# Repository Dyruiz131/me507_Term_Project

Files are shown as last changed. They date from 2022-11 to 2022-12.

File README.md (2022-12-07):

# ME507 Fall 2022 Project: ChessBot

[ChessBot controller code documentation](https://dyruiz131.github.io/me507_Term_Project/)

[ChessBot controller code](https://github.com/Dyruiz131/me507_Term_Project/tree/main/Chessbot)

[ChessBot server repository](https://github.com/sam-hud/ME507-ChessBotServer)

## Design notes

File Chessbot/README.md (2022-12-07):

# ME507 Fall 2022 Project: Chessbot

## Introduction
The project aims to allow two online users to play against each other on a robotically controlled board.

## Documentation
The documentation for the code can be found here:
[ChessBot controller documentation](https://dyruiz131.github.io/me507_Term_Project)

## Webserver
The website controls a custom built API, which the ESP32 communicates with to manage changes to the board.

The webserver repository can be found here:
[ME507-ChessBotServer](https://github.com/sam-hud/ME507-ChessBotServer)

The controller website for the board can accessed [here](https://me507-chessbot.netlify.app).

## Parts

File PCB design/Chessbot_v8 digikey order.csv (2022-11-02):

CART | Qty | Value | Device | Package | Parts | Description | AVAILABILITY | CATEGORY | DESCRIPTION | HEIGHT | MANUFACTURER | MANUFACTURER_NAME | MANUFACTURER_PART_NUMBER | MF | MOUSER_PART_NUMBER | MOUSER_PRICE-STOCK | MP | MPN | OC_FARNELL | OC_NEWARK | OPERATING_TEMP | OPERATING_TEMPERATURE | PACKAGE | PART_STATUS | POPULARITY | PRICE | PURCHASE-URL | ROHS_COMPLIANCE | ROHS_COMPLIANT | SERIES | SPICEPREFIX | SUB-CATEGORY | THERMALLOSS | TYPE
3 | 1 |  | BEAD0805 | 805 | B1 | Ferrite Bead
3 | 1 |  | DCJ0303 | DCJ0303 | 12V_DC | DC POWER JACK |  |  |  |  |  |  |  |  |  |  |  |  | unknown | unknown |  |  |  |  | 20
3 | 1 |  | LEDSMT1206 | 1206 | LED1 | LED |  |  |  |  |  |  |  |  |  |  |  |  |  |  |  |  |  |  | 20
amazon | 1 |  | PINHD-2X2 | 2X02 | LSWITCH | PIN HEADER |  |  |  |  |  |  |  |  |  |  |  |  |  |  |  |  |  |  | 0
10 | 3 | 0.1uF | C-USC0805 | C0805 | C3, C4, C5 | CAPACITOR, American symbol |  |  |  |  |  |  |  |  |  |  |  |  |  |  |  |  |  |  | 63 |  |  |  |  |  | C
10 | 2 | 100uF | CPOL-USE2.5-6 | E2,5-6 | C1, C2 | POLARIZED CAPACITOR, American symbol |  |  |  |  |  |  |  |  |  |  |  |  |  |  |  |  |  |  | 14 |  |  |  |  |  | C
10 | 1 | 100Ω | R-US_R0805 | R0805 | R5 | RESISTOR, American symbol |  |  |  |  |  |  |  |  |  |  |  |  |  |  |  |  |  |  | 85 |  |  |  |  |  | R
10 | 1 | 10kΩ | PV36Z | PV36Z | R1 | Rectangular Trimmer Potentiometers - PV36 Series |  | Resistor | Lead Sealed Type Multiturn PV36 Series |  | BOURNS |  |  |  |  |  |  | PV36Z |  |  |  | -55 to +125 °C |  | Active |  |  |  | RoHS Compliant |  | PV36 |  | Trimpot |  | Lead Sealed
10 | 4 | 10kΩ | R-US_R0805 | R0805 | R2, R6, R7, R8 | RESISTOR, American symbol |  |  |  |  |  |  |  |  |  |  |  |  |  |  |  |  |  |  | 85 |  |  |  |  |  | R
10 | 1 | 180Ω | R-US_R0805 | R0805 | R3 | RESISTOR, American symbol |  |  |  |  |  |  |  |  |  |  |  |  |  |  |  |  |  |  | 85 |  |  |  |  |  | R
10 | 2 | 1N4004 | 1N4004 | DO41-10 | D1, D2 | DIODE |  |  |  |  |  |  |  |  |  |  |  |  |  |  |  |  |  |  | 82
10 | 1 | 1kΩ | R-US_R0805 | R0805 | R4 | RESISTOR, American symbol |  |  |  |  |  |  |  |  |  |  |  |  |  |  |  |  |  |  | 85 |  |  |  |  |  | R
n/a | 1 | KEEYEES_ESP32 | KEEYEES_ESP32 | KEEYEES_ESP32 | ESP32 | Footprint for an add-on board (shield, hat, etc.) for a KeeYees ESP32 development board with ESP-WROOM-32 module. 38 pins.
3 | 1 | LM393D | LM393D | LM393D | U$2
amazon | 2 | PINHD-1X2 | PINHD-1X2 | 1X02 | 5V_JUMP, ELECTROMAGNET | PIN HEADER |  | CONNECTOR |  |  |  |  |  |  |  |  |  |  |  |  |  |  |  |  |  |  |  |  |  |  |  | PIN-HEADER
amazon | 3 | PINHD-1X4 | PINHD-1X4 | 1X04 | MPM3610, STEPPER1, STEPPER2 | PIN HEADER |  | CONNECTOR |  |  |  |  |  |  |  |  |  |  |  |  |  |  |  |  |  |  |  |  |  |  |  | PIN-HEADER
amazon | 1 | PINHD-2X2 | PINHD-2X2 | 2X02 | TCRT5000 | PIN HEADER |  | CONNECTOR |  |  |  |  |  |  |  |  |  |  |  |  |  |  |  |  |  |  |  |  |  |  |  | PIN-HEADER
4 | 1 | PMV16XNR | PMV16XNR | SOT95P230X110-3N | Q1 | Nexperia PMV16XNR N-channel MOSFET, 8.6 A, 20 V PMV16XN, 3-Pin SOT-23 |  |  | Nexperia PMV16XNR N-channel MOSFET, 8.6 A, 20 V PMV16XN, 3-Pin SOT-23 | 1.1mm |  | Nexperia | PMV16XNR |  | 771-PMV16XNR | https://www.mouser.co.uk/ProductDetail/Nexperia/PMV16XNR?qs=%252BRKXB2WKlSfp5fVW5DDV6w%3D%3D
amazon | 2 | TMC2208_SILENTSTEPSTICK | TMC2208_SILENTSTEPSTICK | MODULE_TMC2208_SILENTSTEPSTICK | DRIVER1, DRIVER2 | TMC2208 Motor Controller/Driver, Stepper Power Management Evaluation Board Check availability | In Stock |  | TMC2208 Motor Controller/Driver, Stepper Power Management Evaluation Board |  |  |  |  | Trinamic Motion |  |  | TMC2208 SILENTSTEPSTICK |  |  |  |  |  | None |  |  | None | https://pricing.snapeda.com/search/part/TMC2208 SILENTSTEPSTICK/?ref=eda

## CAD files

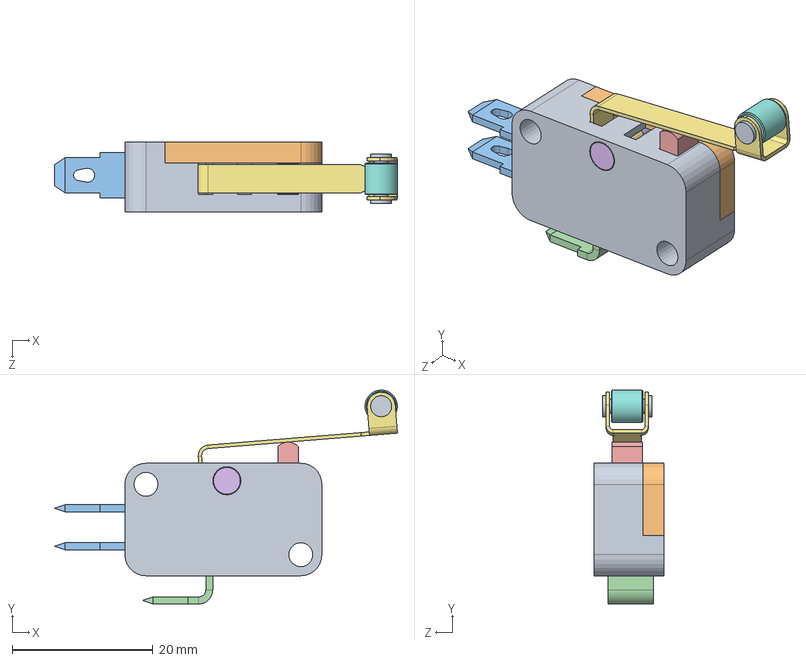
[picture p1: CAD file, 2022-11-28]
CAD/Assembly - V-156-1C25 micro switch.SLDASM
48.7 x 30.4 x 10.0 mm
Cover
Connector - straight x 2
Connector - bent
Switch
Rivet - long
Arm
Roll
Rivet - short

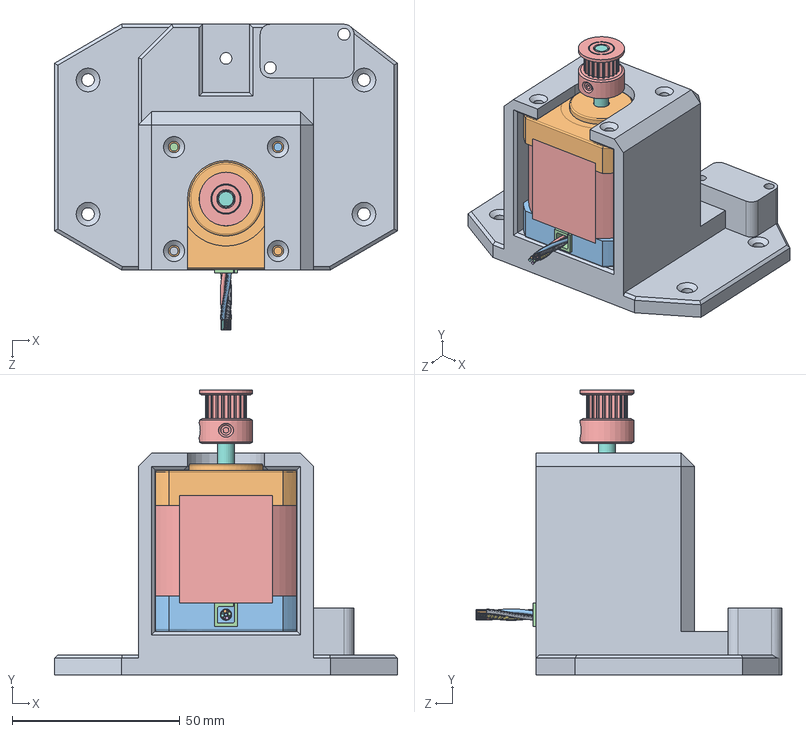
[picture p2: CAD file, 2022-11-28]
CAD/Stepper mount assembly.SLDASM
102.3 x 85.0 x 91.1 mm
platform rail mount stepper
Frontplate.step
Backplate.step
Connenctor.step
Housing.step
Bearing dummy.step
Bearing dummy 01.step
Core.step
M3x40-Screw.step
M3x40-Screw001.step
M3x40-Screw002.step
M3x40-Screw003.step
Cable-1of4.step
Copper-1of4.step
Cable-2of4.step
Copper-4of4.step
Cable-3of4.step
Copper-3of4.step
Cable-4of4.step
Copper-2of4.step
GT2_20T

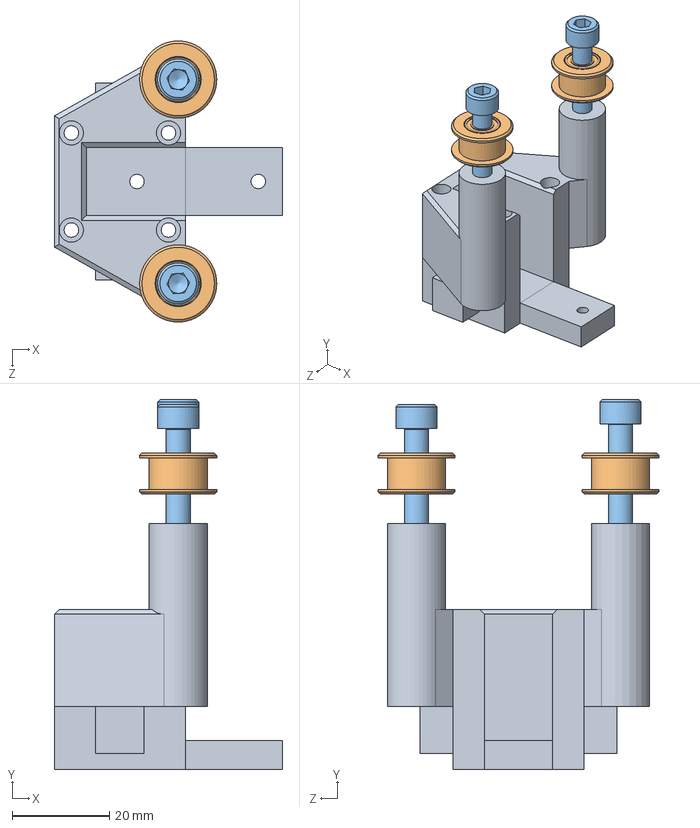
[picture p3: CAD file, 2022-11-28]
CAD/rail to rail sliding idler mount assembly.SLDASM
47.0 x 76.2 x 57.9 mm
rail rail mount
GT2 idler pulley (5 mm bore) v1 x 2
socket head cap screw_am x 2

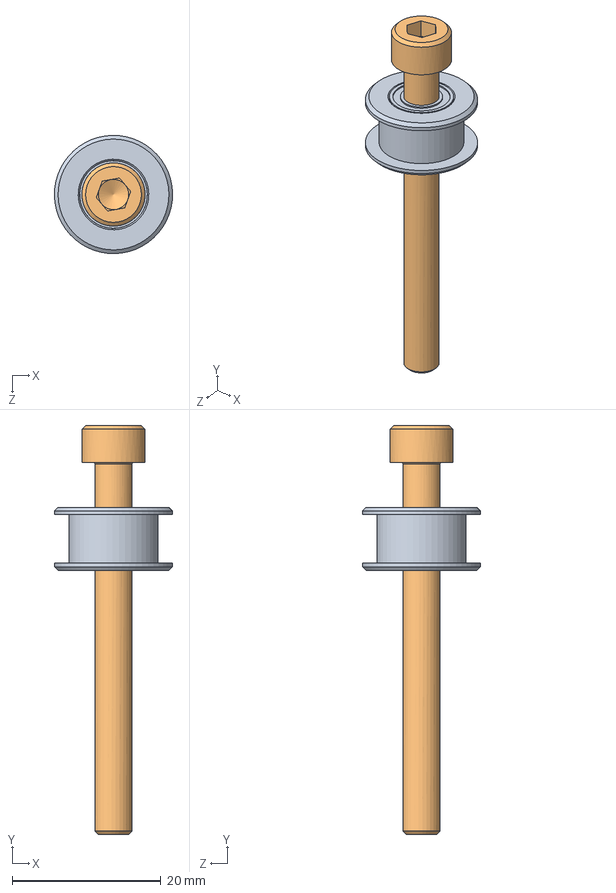
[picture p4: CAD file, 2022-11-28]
CAD/platform idler mount assembly.SLDASM
15.9 x 55.0 x 15.9 mm
GT2 idler pulley (5 mm bore) v1
socket head cap screw_am

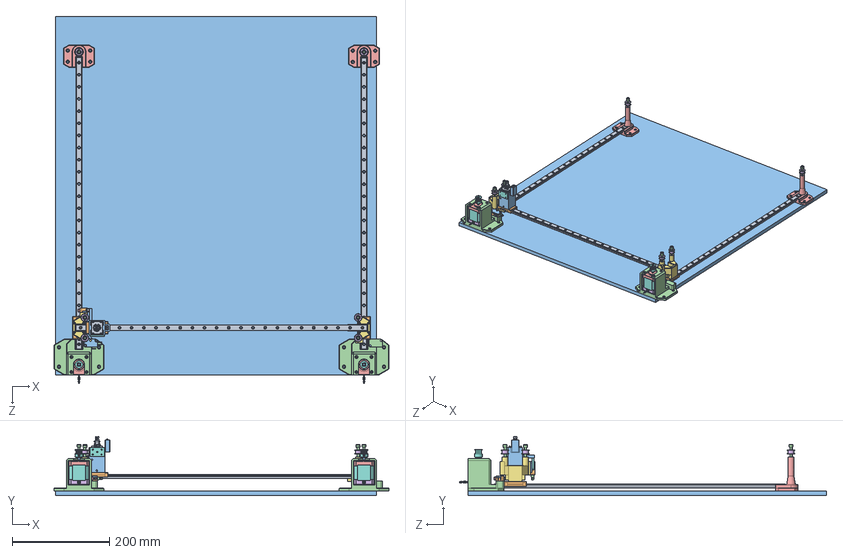
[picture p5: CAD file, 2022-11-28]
CAD/507_Chess_Bot.SLDASM
689.3 x 122.0 x 755.8 mm
MGN12 LINEAR GUIDE RAIL, 600 mm x 3
MGN12H, LINEAR GUIDE BLOCK x 3
platform rail mount stepper x 2
Frontplate.step x 2
Backplate.step x 2
Connenctor.step x 2
Housing.step x 2
Bearing dummy.step x 2
Bearing dummy 01.step x 2
Core.step x 2
M3x40-Screw.step x 2
M3x40-Screw001.step x 2
M3x40-Screw002.step x 2
M3x40-Screw003.step x 2
Cable-1of4.step x 2
Copper-1of4.step x 2
Cable-2of4.step x 2
Copper-4of4.step x 2
Cable-3of4.step x 2
Copper-3of4.step x 2
Cable-4of4.step x 2
Copper-2of4.step x 2
GT2_20T x 2
Solenoid JF-0826B
Cover x 2
Connector - straight x 4
Connector - bent x 2
Switch x 2
Rivet - long x 2
Arm x 2
Roll x 2
Rivet - short x 2
Solenoid Mount
socket head cap screw_am x 7
platform rail mount x 2
GT2 idler pulley (5 mm bore) v1 x 6
rail rail mount x 2
Belt Clamp
TCR5000L

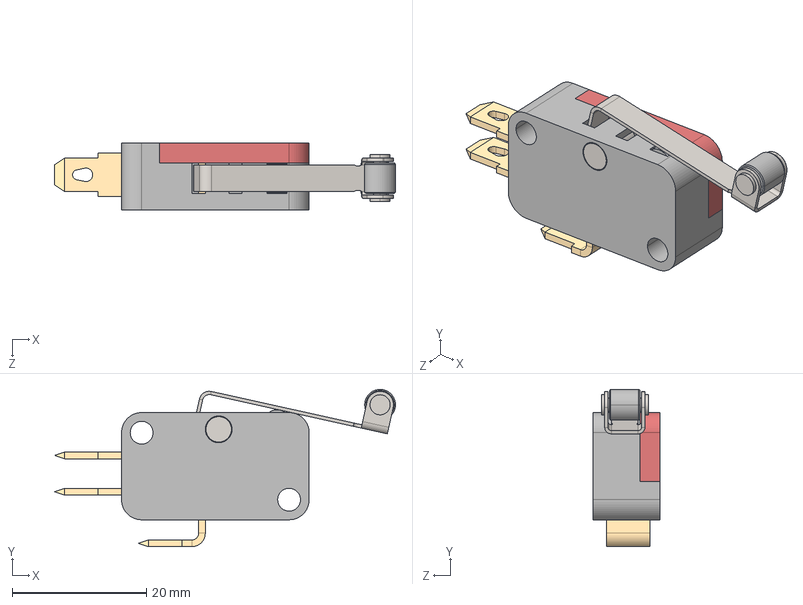
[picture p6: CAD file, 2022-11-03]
CAD/V-156-1C25/Assembly - V-156-1C25 micro switch (Pressed).STEP
50.9 x 23.5 x 10.0 mm
Cover
Connector - straight x 2
Connector - bent
Switch
Rivet - long
Arm
Roll
Rivet - short

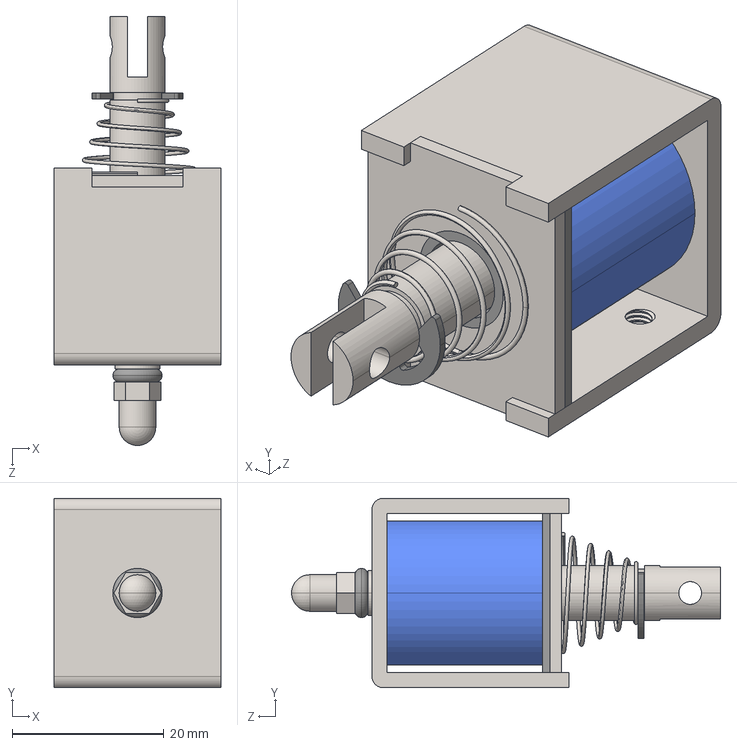
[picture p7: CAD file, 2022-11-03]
CAD/linear actuator/Solenoid JF-0826B.STEP
22.0 x 25.0 x 56.6 mm

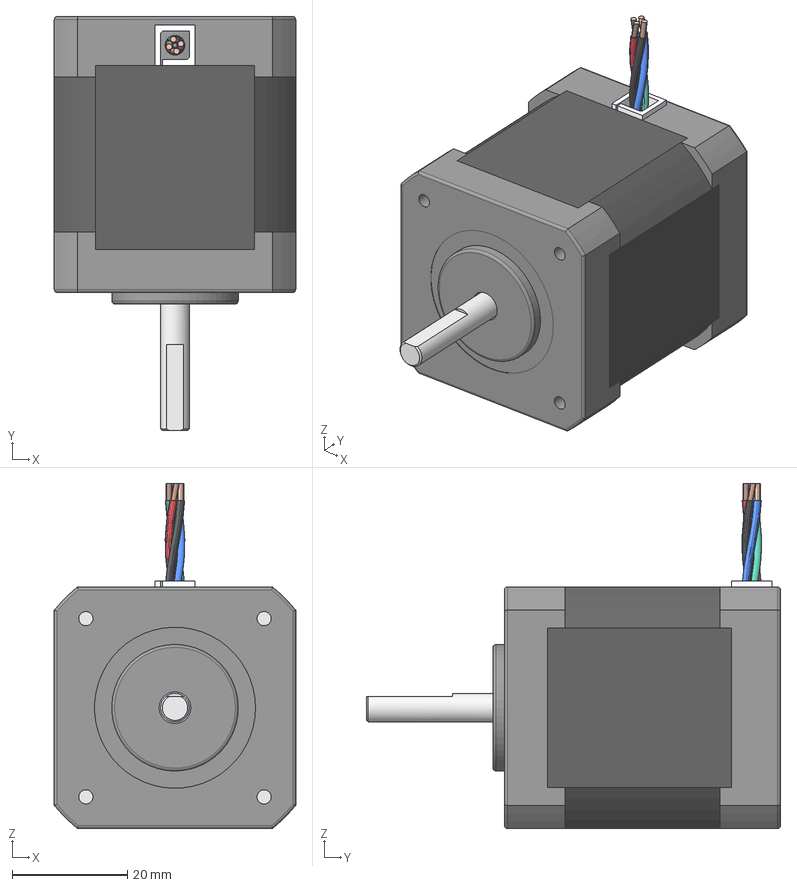
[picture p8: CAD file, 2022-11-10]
CAD/nema17-x-48-1/NEMA17 x 48.step
42.0 x 72.0 x 60.0 mm
Frontplate
Backplate
Connenctor
Housing
Bearing dummy
Bearing dummy 01
Core
M3x40-Screw
M3x40-Screw001
M3x40-Screw002
M3x40-Screw003
Cable-1of4
Copper-1of4
Cable-2of4
Copper-4of4
Cable-3of4
Copper-3of4
Cable-4of4
Copper-2of4

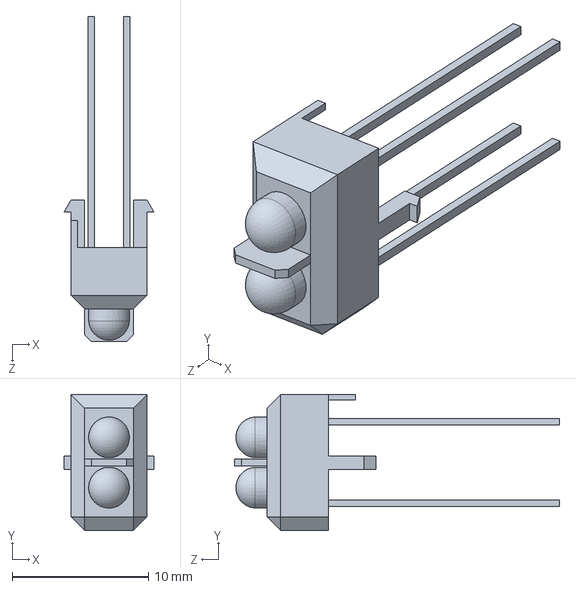
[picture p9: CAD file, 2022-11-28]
CAD/TCRT5000L/tcrt5000l-1/TCR5000L.SLDPRT
6.60 x 10.0 x 23.9 mm

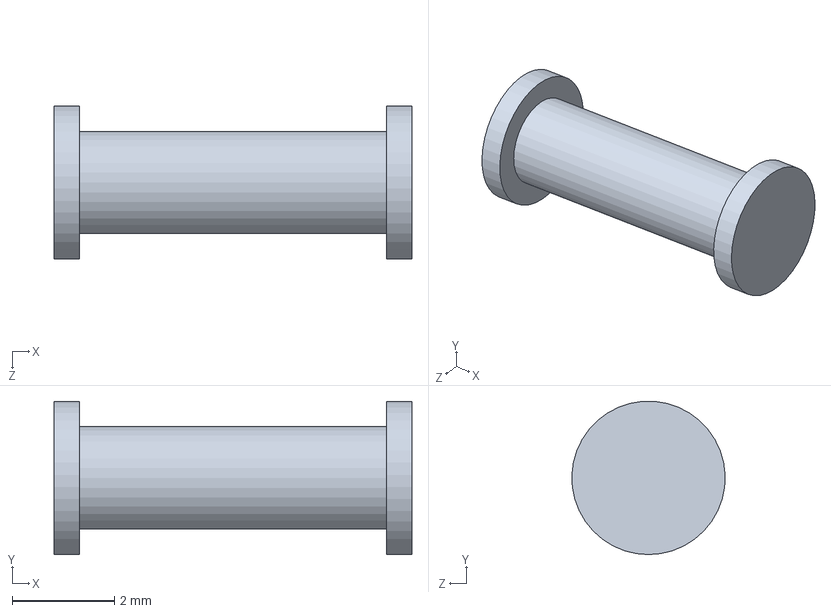
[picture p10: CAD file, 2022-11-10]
CAD/V-156-1C25/Rivet - short.SLDPRT
7.00 x 3.00 x 3.00 mm

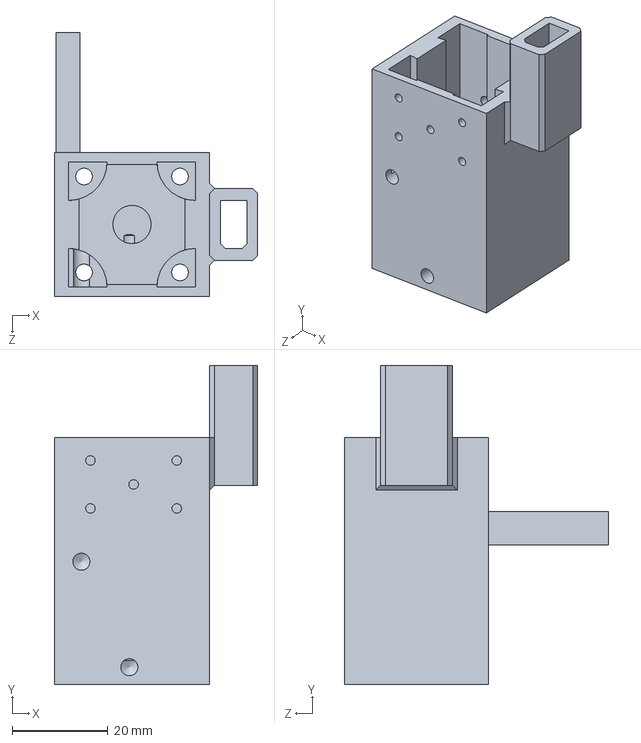
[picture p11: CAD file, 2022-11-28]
CAD/Solenoid Mount.SLDPRT
42.4 x 66.5 x 55.0 mm

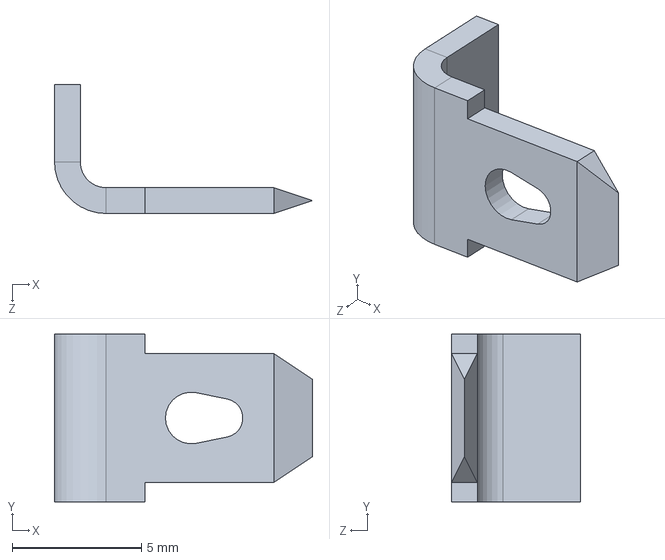
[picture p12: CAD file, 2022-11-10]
CAD/V-156-1C25/Connector - bent.SLDPRT
10.0 x 6.50 x 5.00 mm

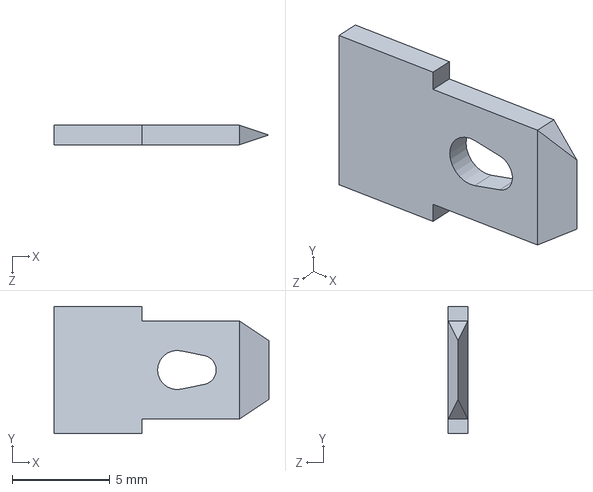
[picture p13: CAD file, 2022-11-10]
CAD/V-156-1C25/Connector - straight.SLDPRT
11.0 x 6.50 x 1.00 mm

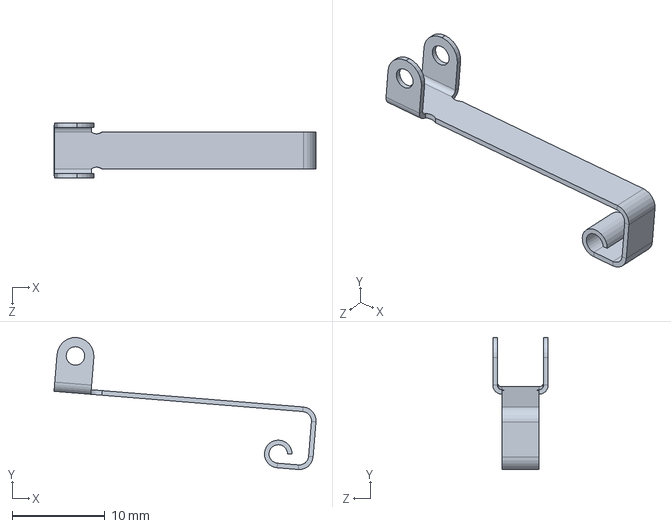
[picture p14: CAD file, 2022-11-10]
CAD/V-156-1C25/Arm.SLDPRT
28.3 x 14.3 x 6.00 mm

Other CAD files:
CAD/V-156-1C25/Assembly - V-156-1C25 micro switch.SLDASM
CAD/V-156-1C25/Assembly - V-156-1C25 micro switch (Idle).STEP
CAD/V-156-1C25/Roll.SLDPRT
CAD/rail rail mount.SLDPRT
CAD/Belt Clamp.SLDPRT
CAD/Belt Clamp.STL
CAD/GT2 idler pulley (5 mm bore) v1.SLDPRT
CAD/GT2_20T.SLDPRT
CAD/MGN12 LINEAR GUIDE RAIL, 600 mm.SLDPRT
CAD/MGN12H, LINEAR GUIDE BLOCK.SLDPRT
CAD/Solenoid Mount.STL
CAD/V-156-1C25/Body.SLDPRT
CAD/V-156-1C25/Cover.SLDPRT
CAD/V-156-1C25/Rivet - long.SLDPRT
CAD/V-156-1C25/Switch.SLDPRT
CAD/game board.SLDPRT
CAD/linear actuator/Solenoid JF-0826B.SLDPRT
CAD/nema17-x-48-1/NEMA17 x 48.SLDASM
CAD/platform base.SLDPRT
CAD/platform rail mount stepper bracket.SLDPRT
CAD/platform rail mount stepper.SLDPRT
CAD/platform rail mount stepper1.STL
CAD/platform rail mount stepper2.STL
CAD/platform rail mount.SLDPRT
CAD/platform rail mount1.STL

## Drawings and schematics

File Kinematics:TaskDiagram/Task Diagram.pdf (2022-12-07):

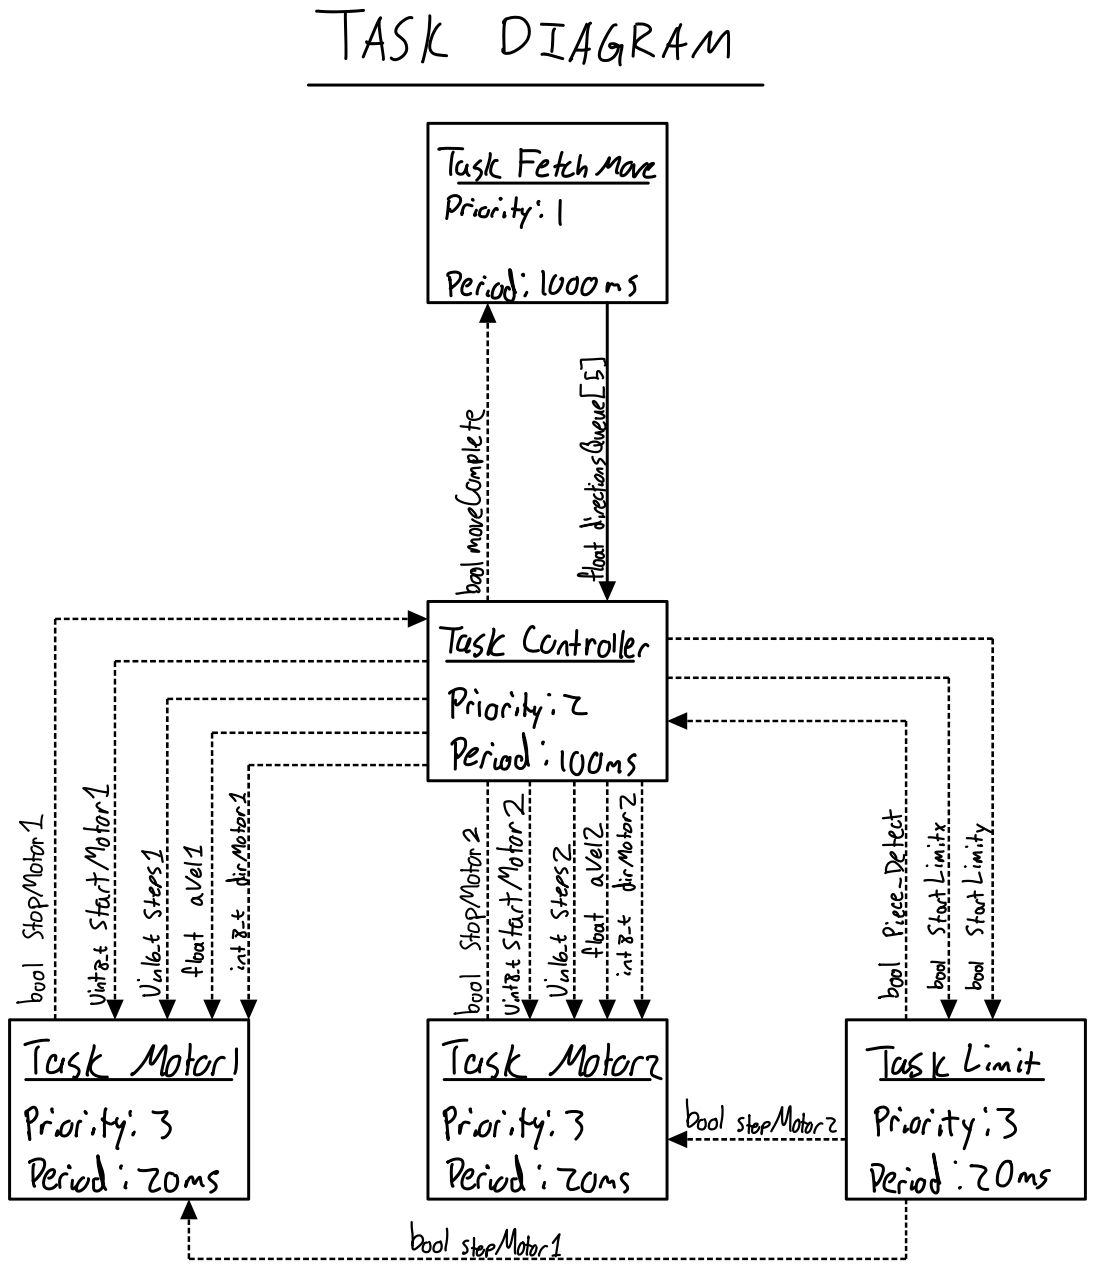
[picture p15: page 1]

## 11: Move GridY

## 13: Release

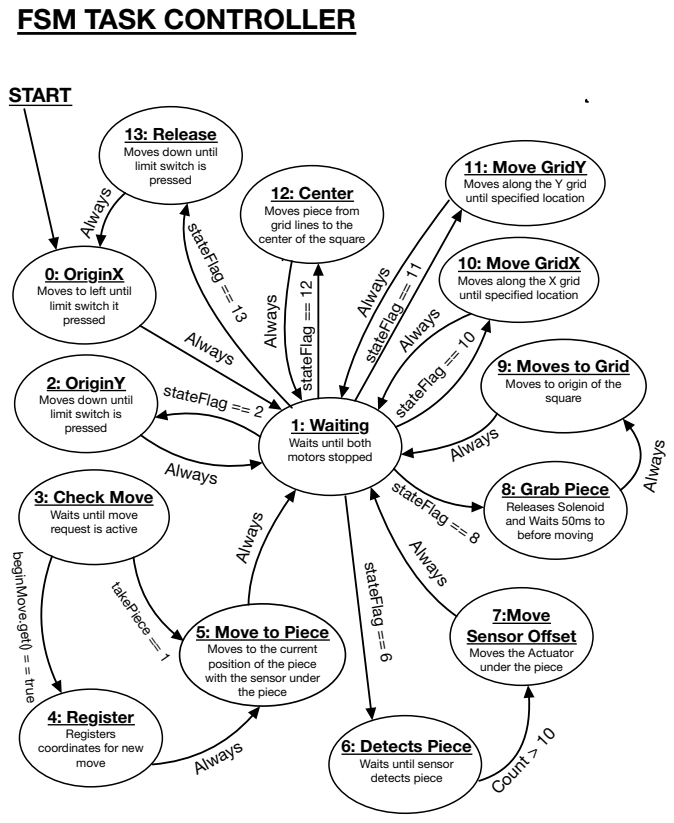
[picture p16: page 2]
takePiece == 1; stateFlag == 6; Count > 10; Always; stateFlag == 10; stateFlag == 2; START; stateFlag == 11; stateFlag == 12; stateFlag == 13

FSM TASK CONTROLLER

Moves down until
limit switch is
pressed

12: Center
Moves piece from
grid lines to the
center of the square

Moves along the Y grid
until specified location

10: Move GridX
Moves along the X grid

0: OriginX
Moves to left until
limit switch it

9: Moves to Grid
Moves to origin of the
square

2: OriginY

1: Waiting
Waits until both
motors stopped

before moving stateFlag == 8

8: Grab Piece
Releases Solenoid
and Waits 50ms to

3: Check Move
Waits until move
request is active

beginMove.get() = = true

7:Move
Sensor Offset
Moves the Actuator
under the piece

5: Move to Piece
Moves to the current
position of the piece
with the sensor under
the piece

4: Register
Registers
coordinates for new
move

6: Detects Piece
Waits until sensor
detects piece

# START

# FSM TASK MOTOR

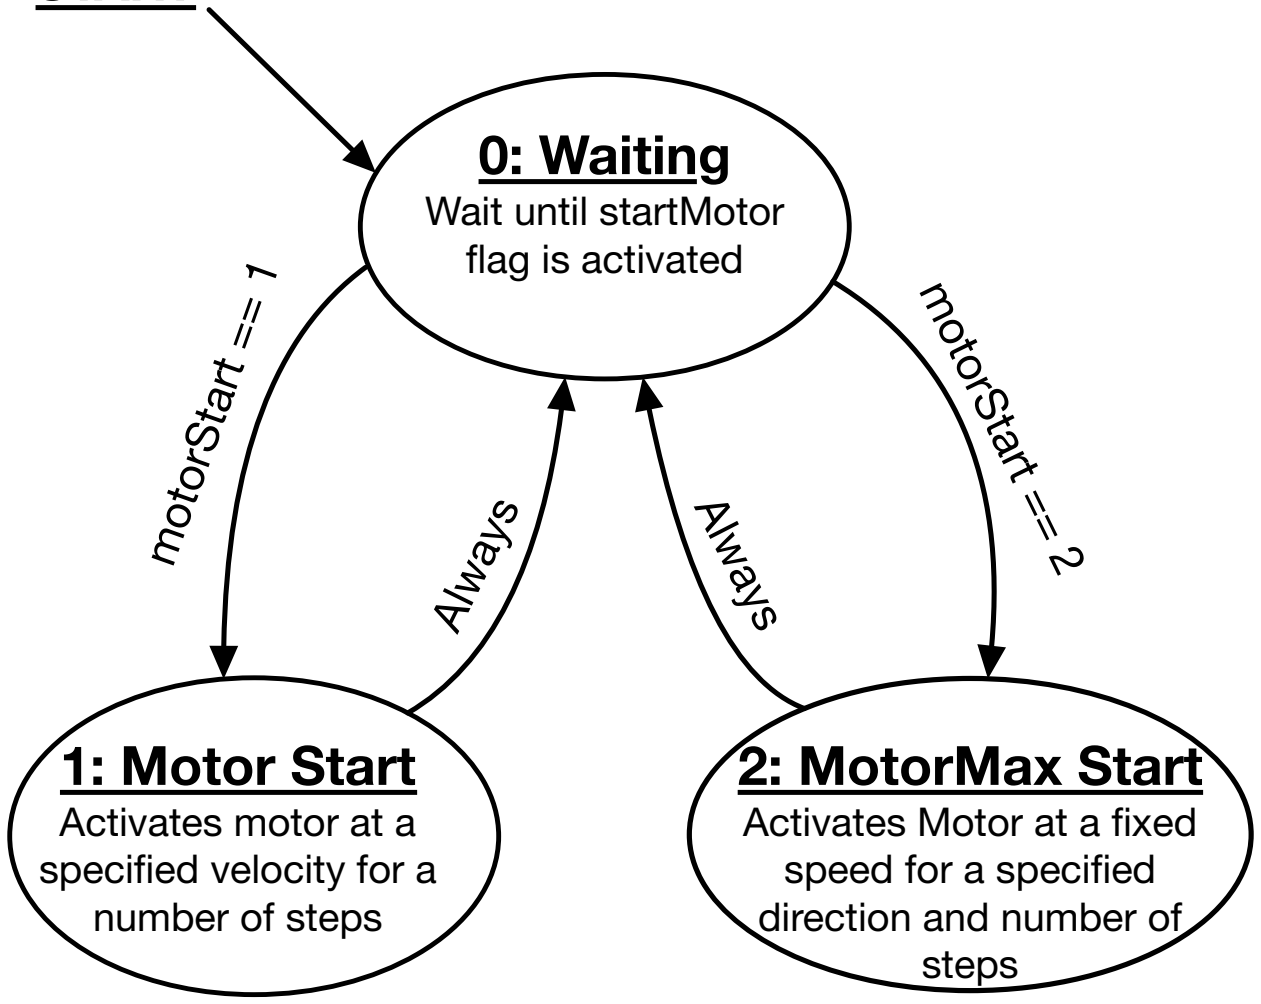
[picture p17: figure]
1: Motor Start Activates motor at a specified velocity for a number of steps; 0: Waiting Wait until startMotor flag is activated; Always; motorStart == 1; motorStart == 2; 2: MotorMax Start Activates Motor at a fixed speed for a specified direction and number of steps

# START

# FSM TASK LIMIT

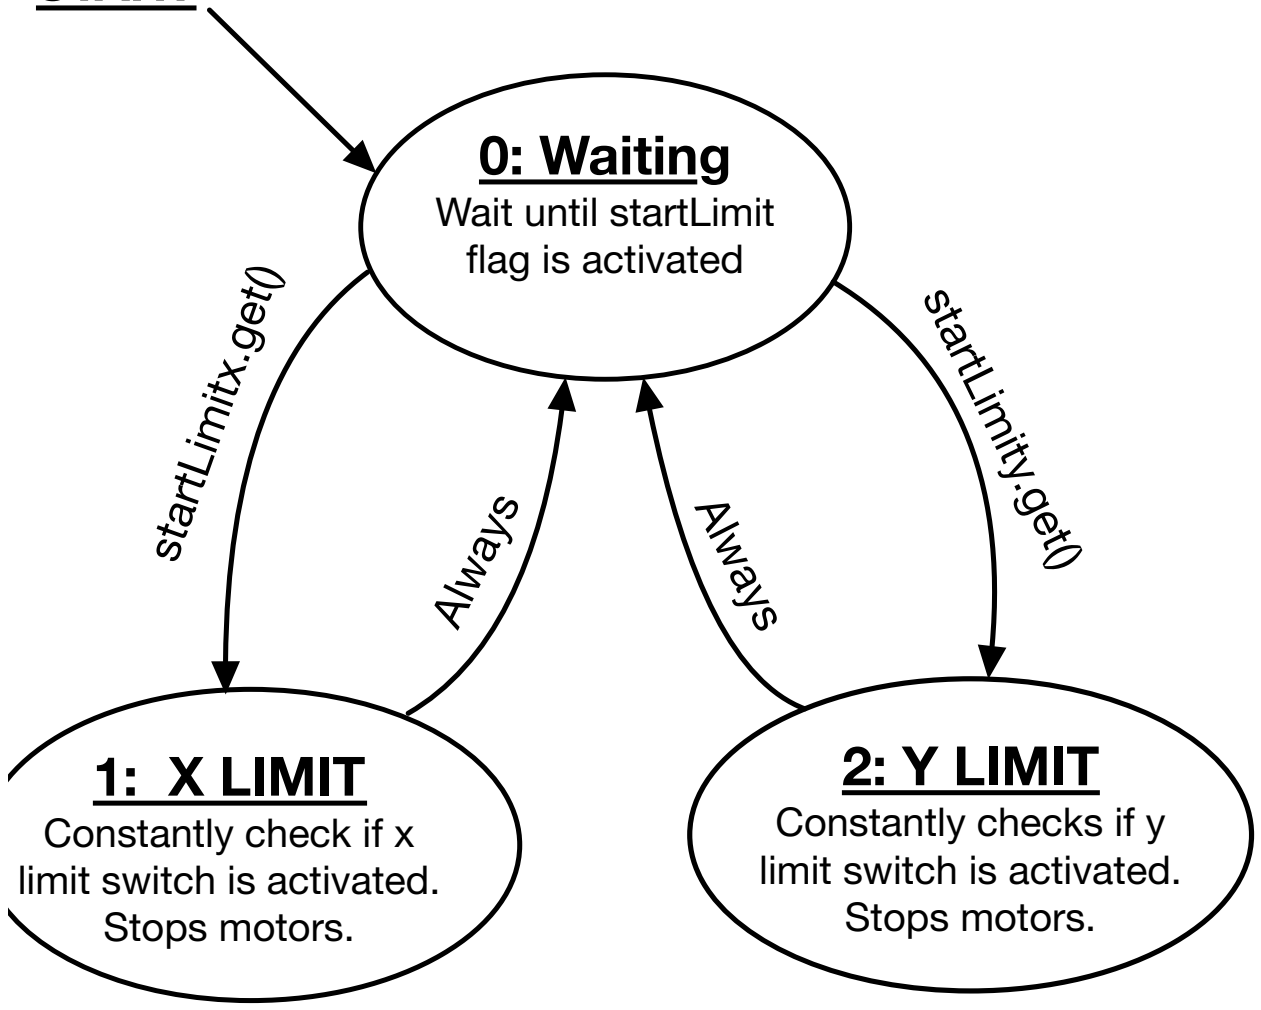
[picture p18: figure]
Always; 0: Waiting Wait until startLimit flag is activated; 1: X LIMIT Constantly check if x limit switch is activated. Stops motors.; startLimitx.get(); startLimity.get(); 2: Y LIMIT Constantly checks if y limit switch is activated. Stops motors.

# START

# FSM TASK FETCH MOVE

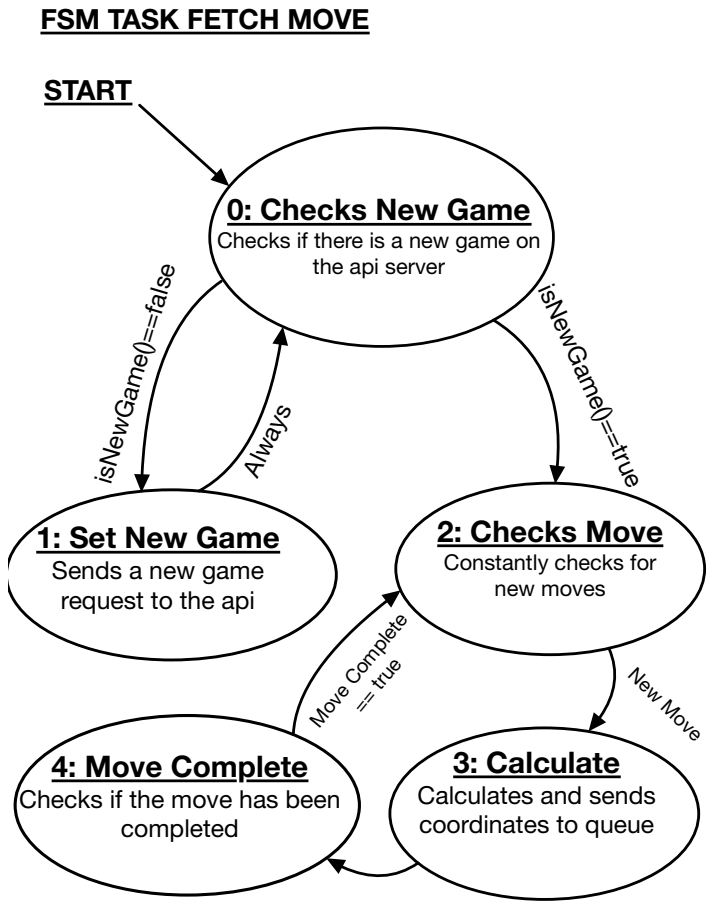
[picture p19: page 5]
isNewGame()==false; isNewGame()==true; Always; completed; New Move; Move Complete; == true

0: Checks New Game
Checks if there is a new game on

the api server

1: Set New Game
Sends a new game
request to the api

2: Checks Move
Constantly checks for
new moves

4: Move Complete
Checks if the move has been

3: Calculate
Calculates and sends
coordinates to queue

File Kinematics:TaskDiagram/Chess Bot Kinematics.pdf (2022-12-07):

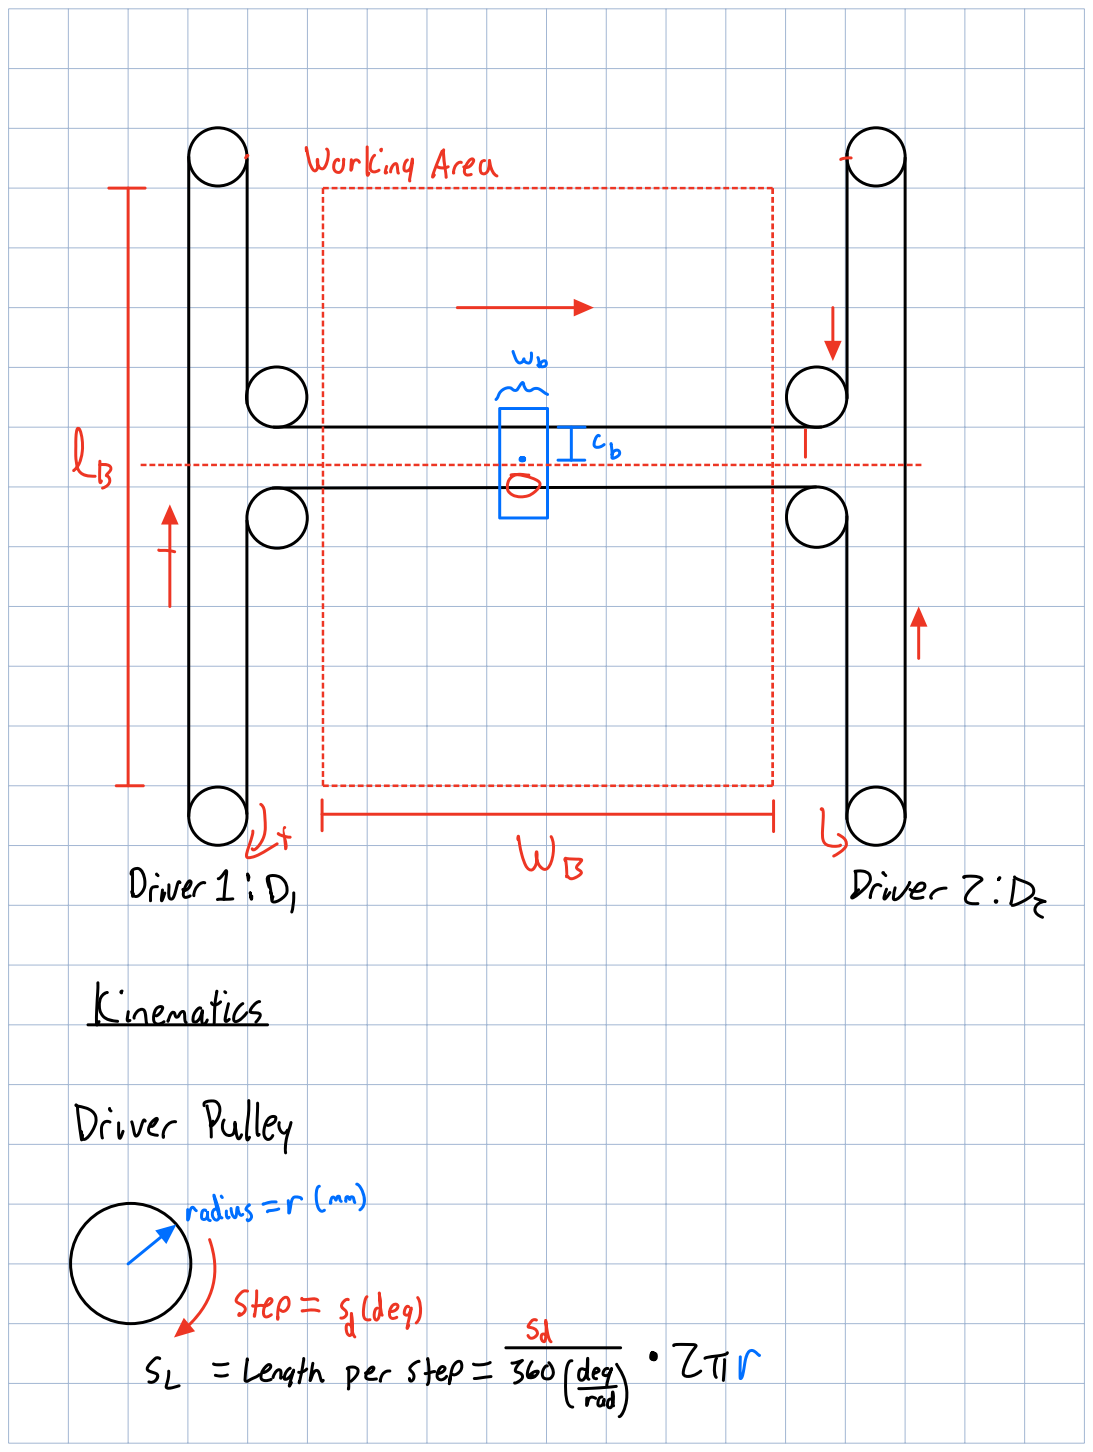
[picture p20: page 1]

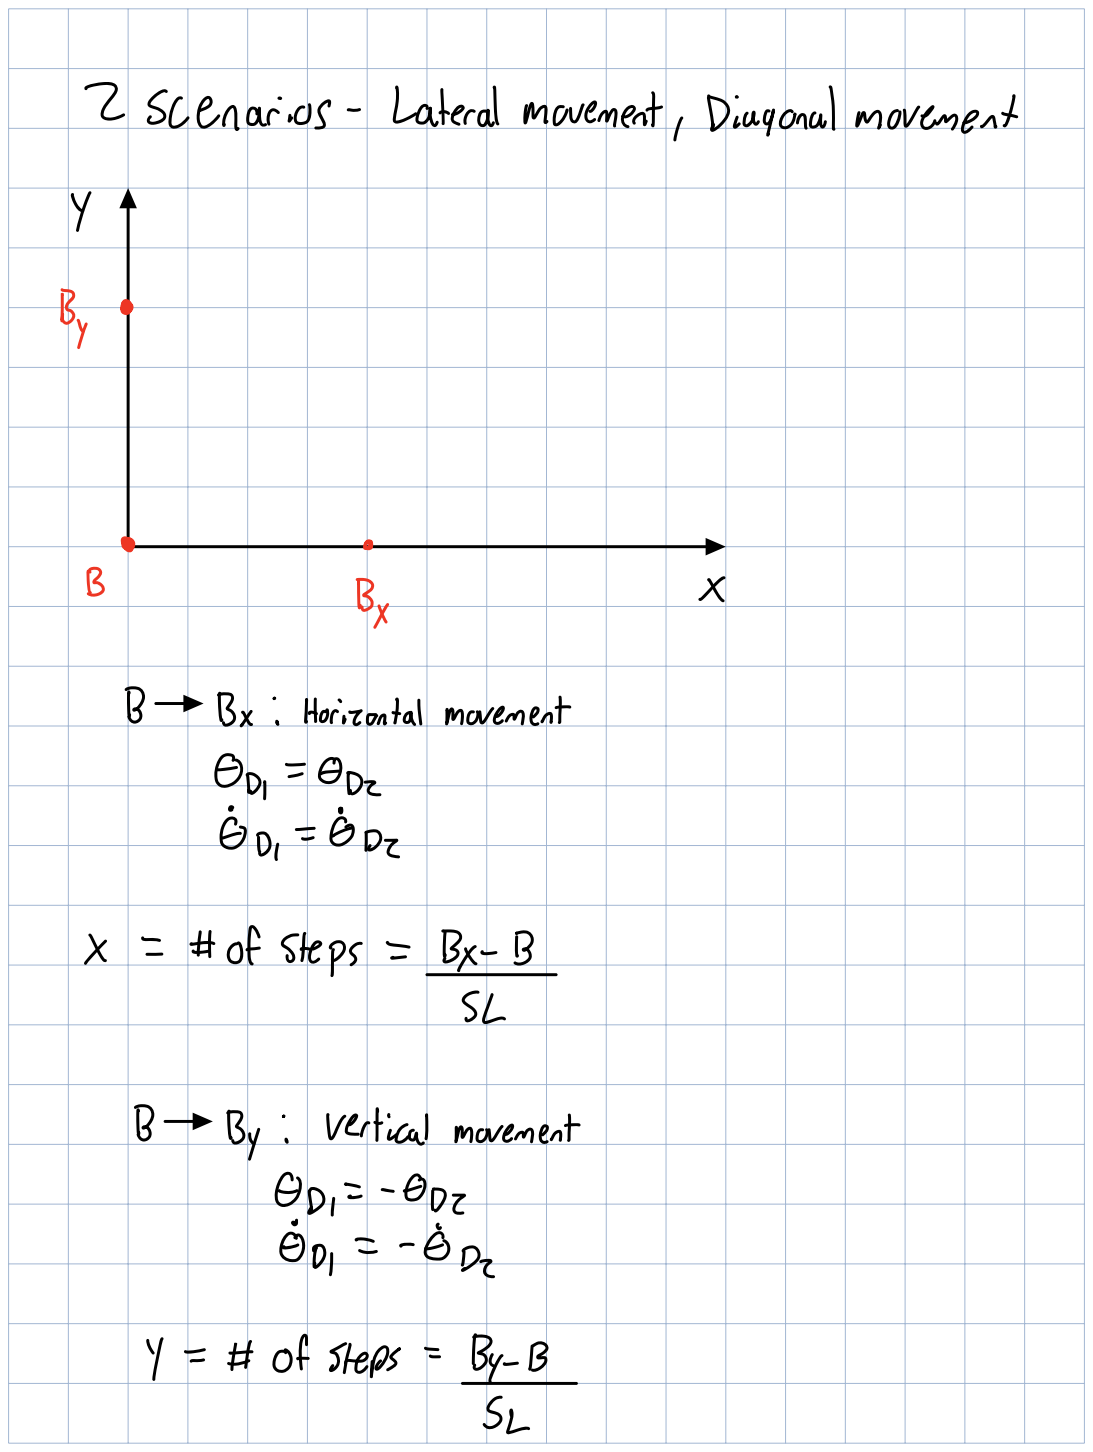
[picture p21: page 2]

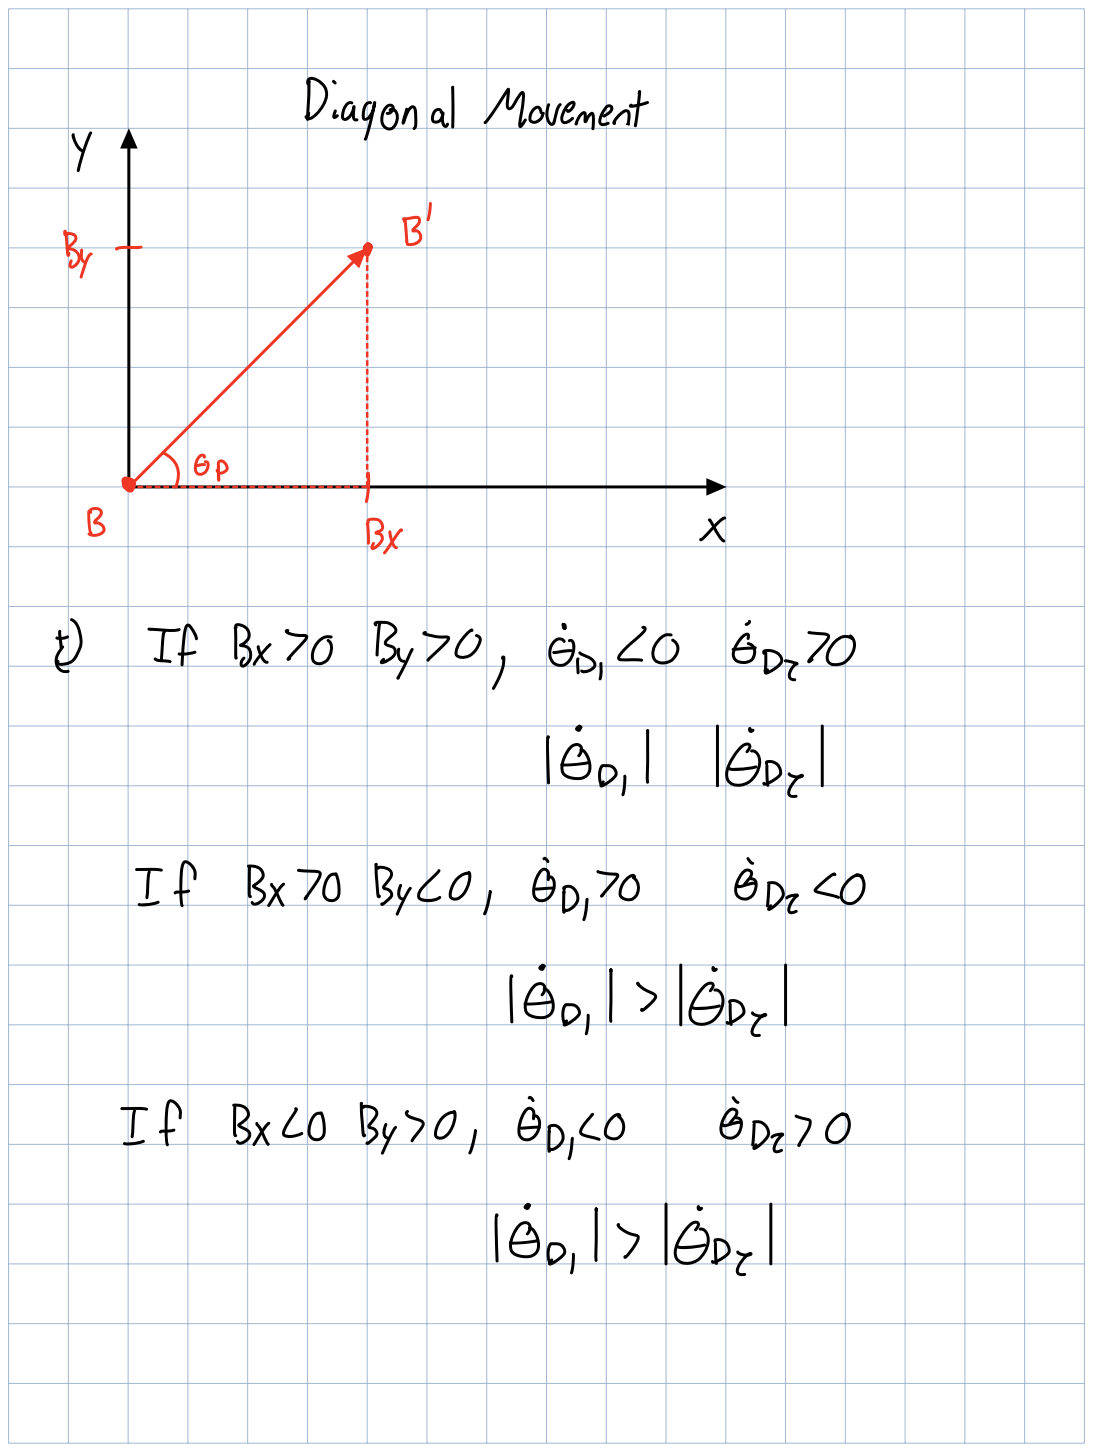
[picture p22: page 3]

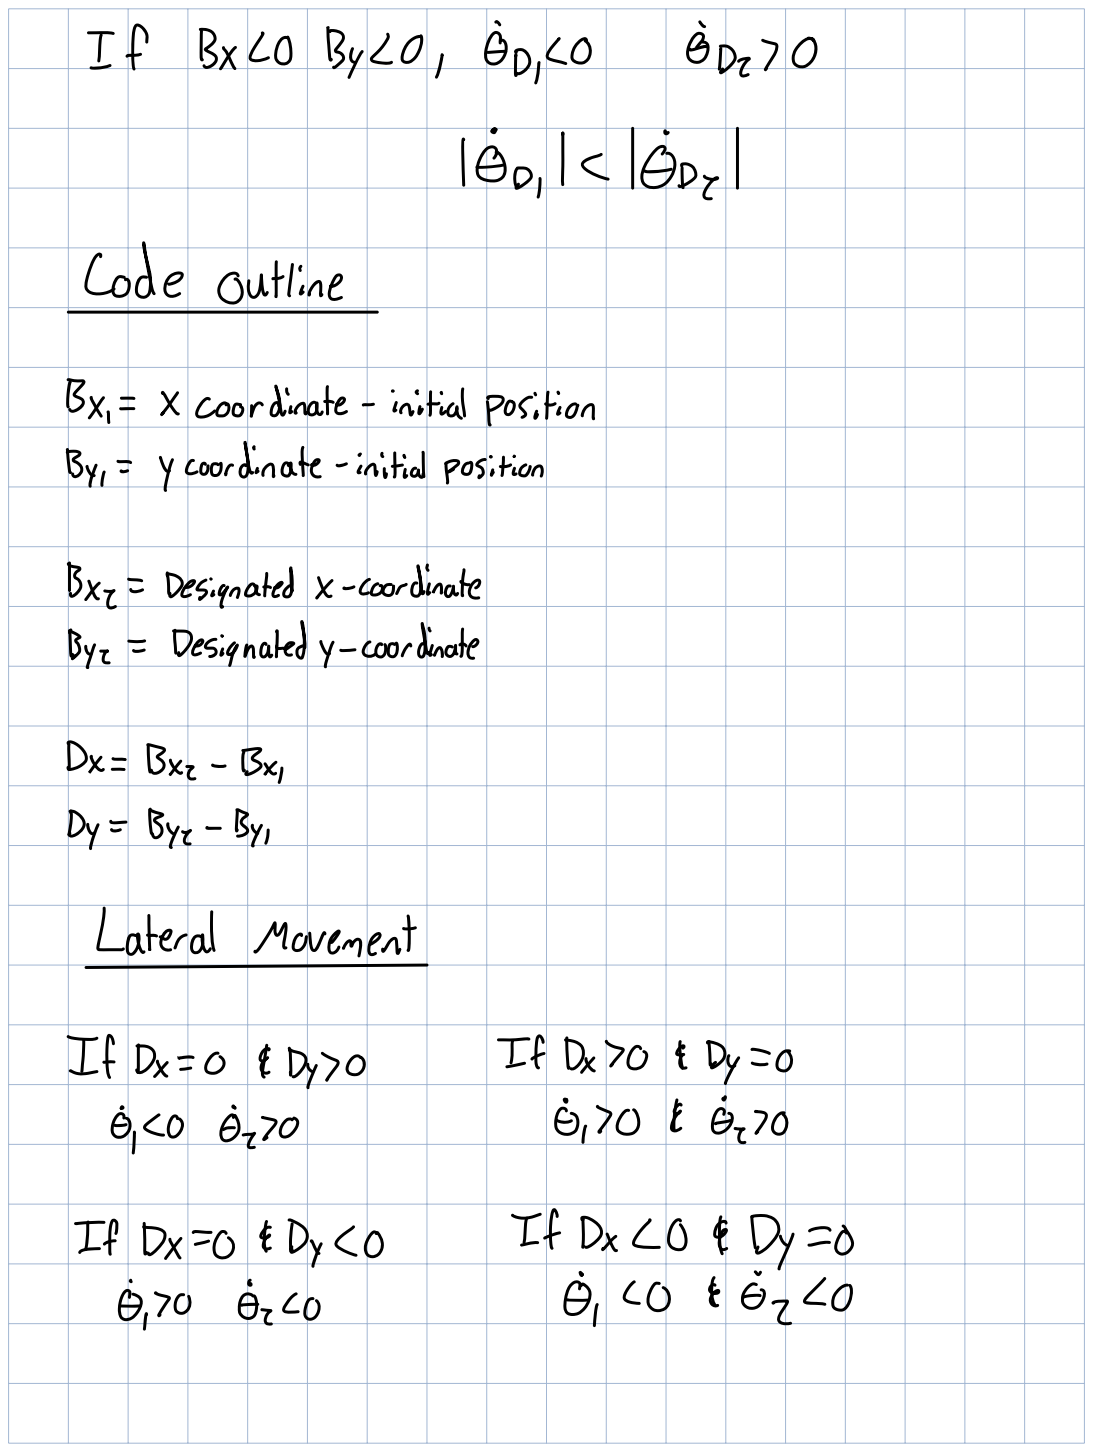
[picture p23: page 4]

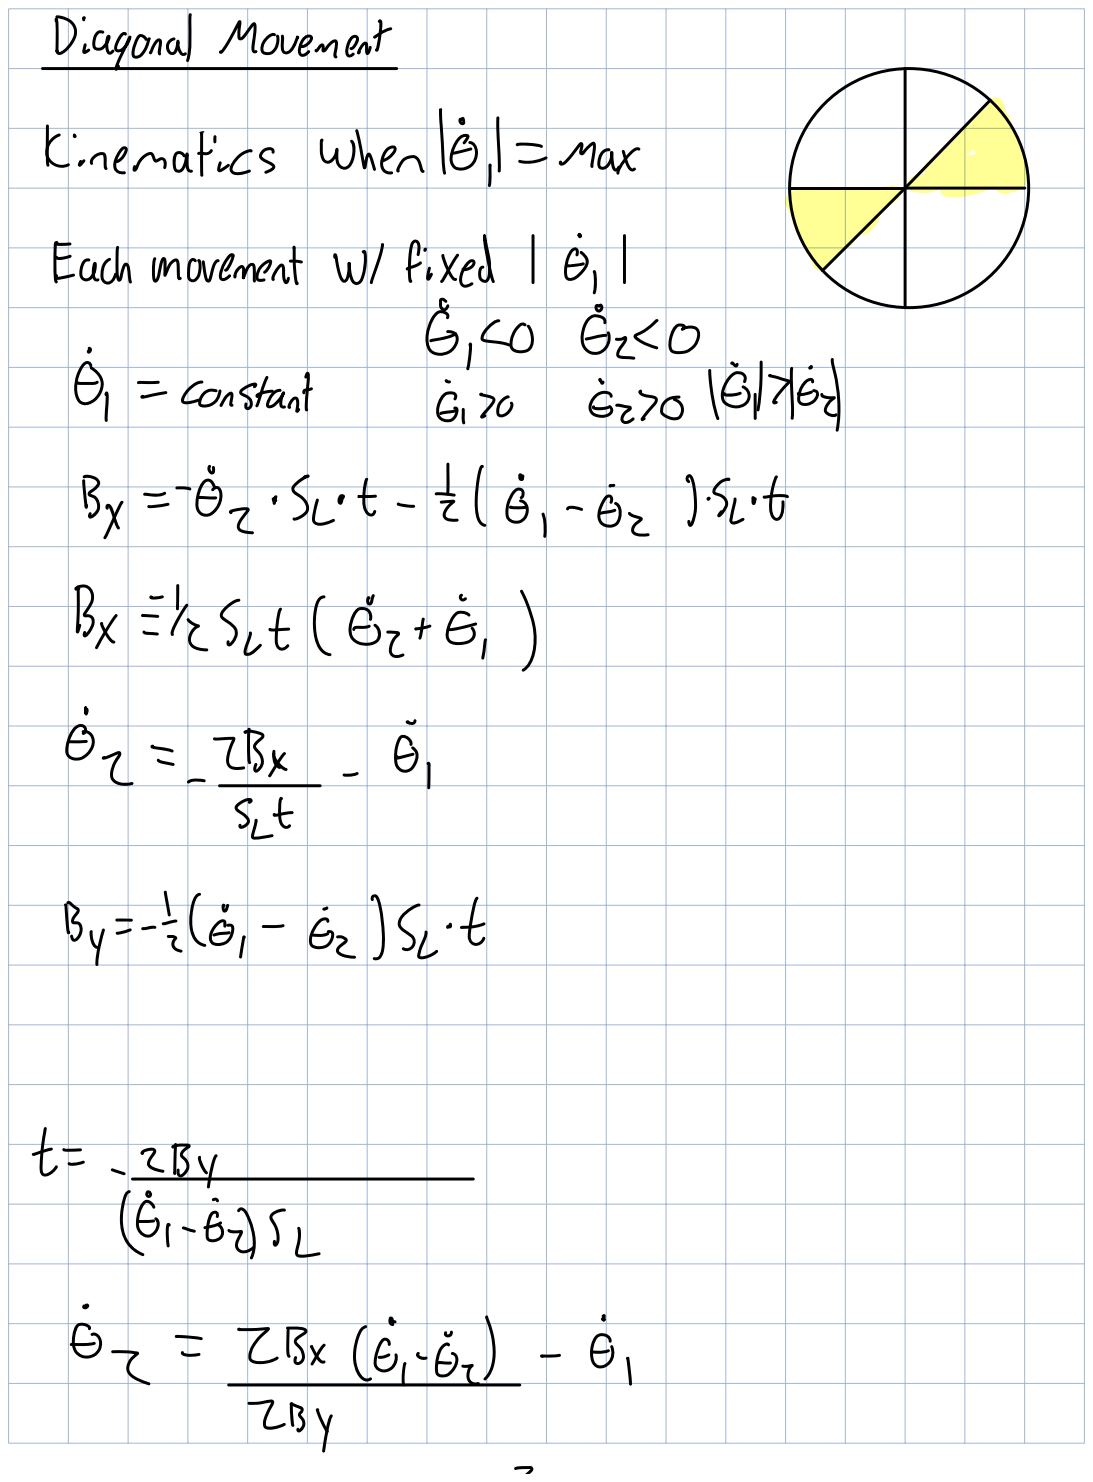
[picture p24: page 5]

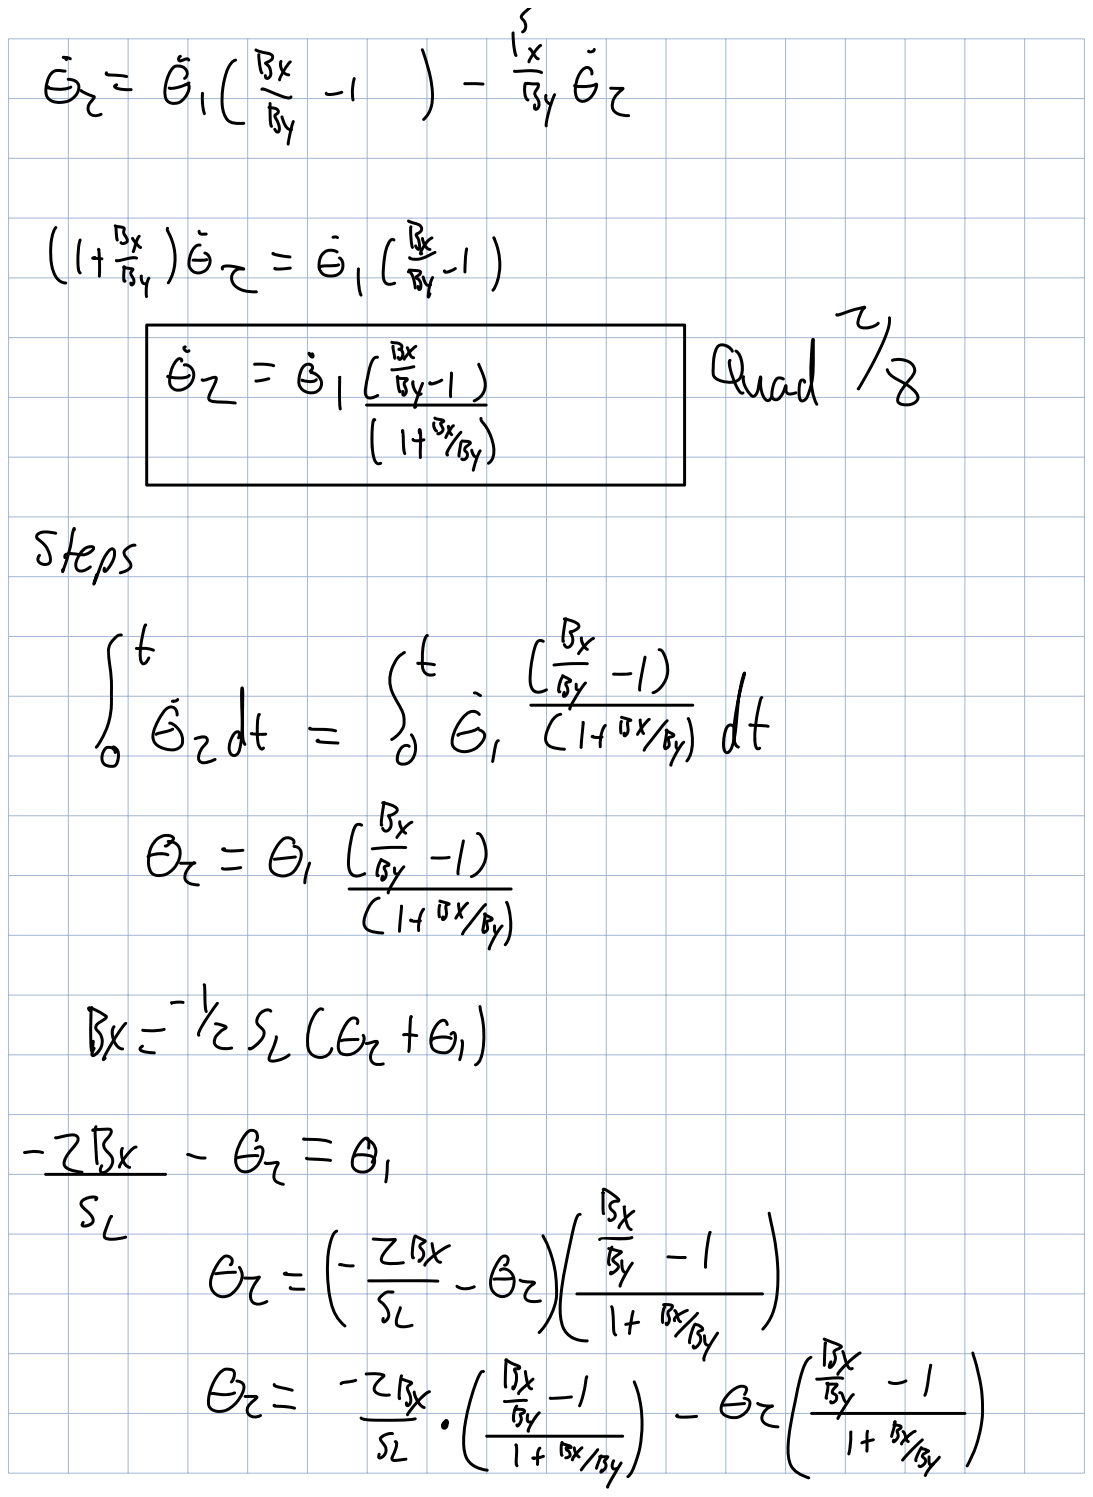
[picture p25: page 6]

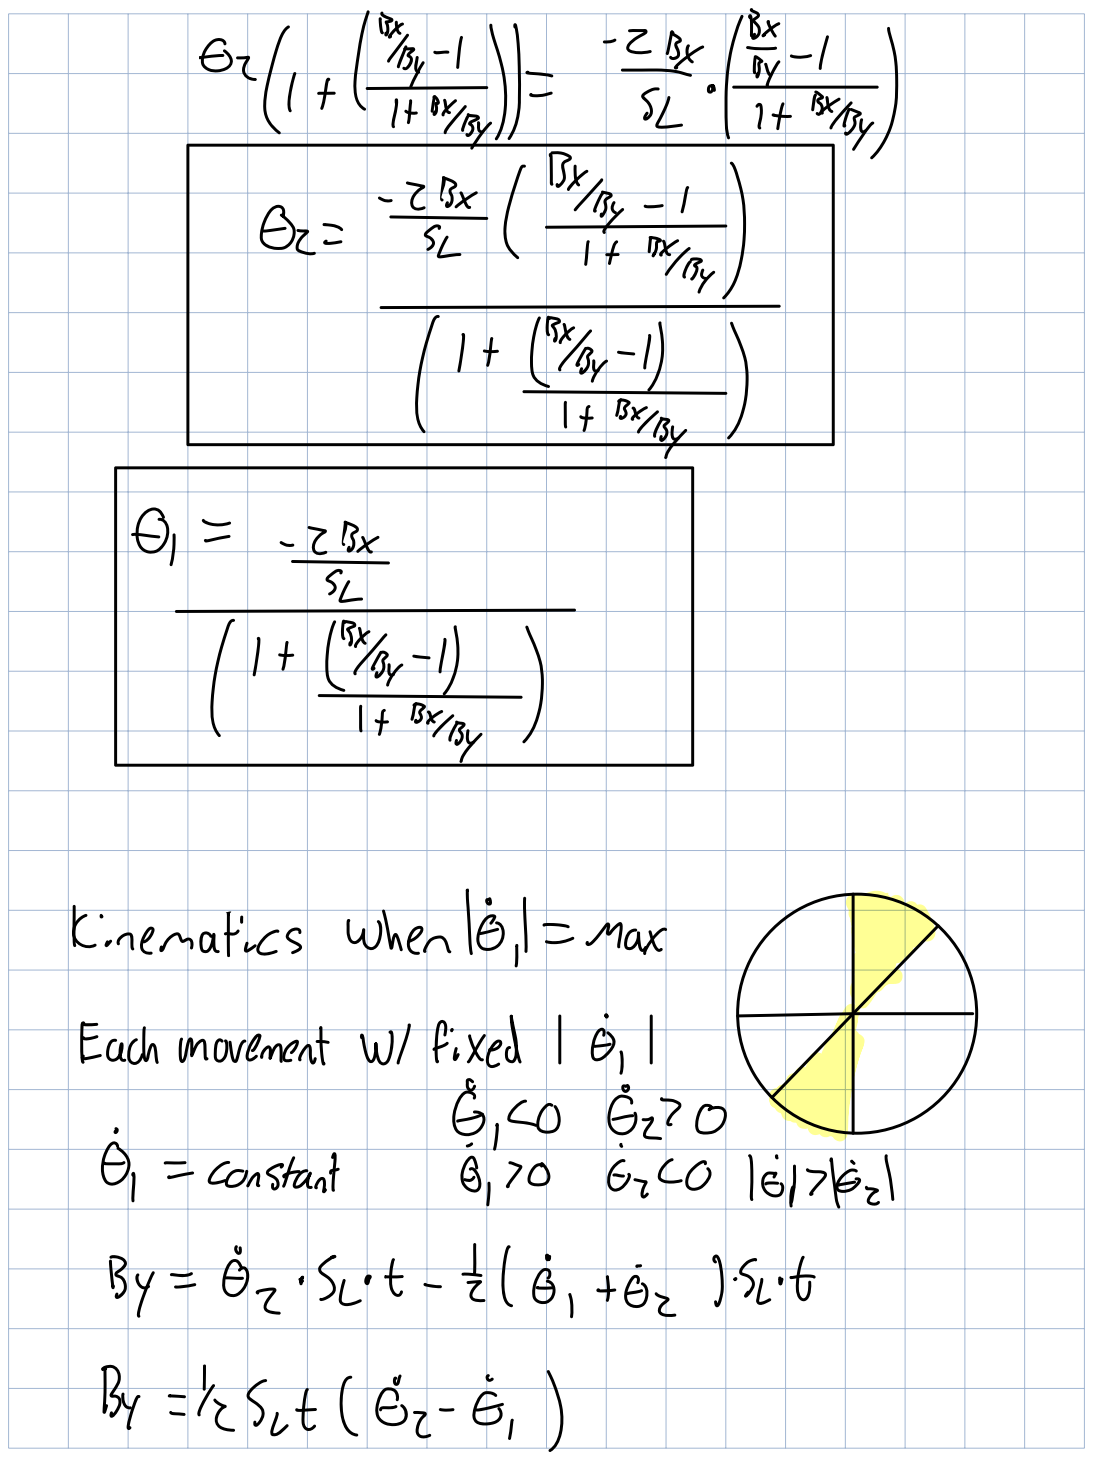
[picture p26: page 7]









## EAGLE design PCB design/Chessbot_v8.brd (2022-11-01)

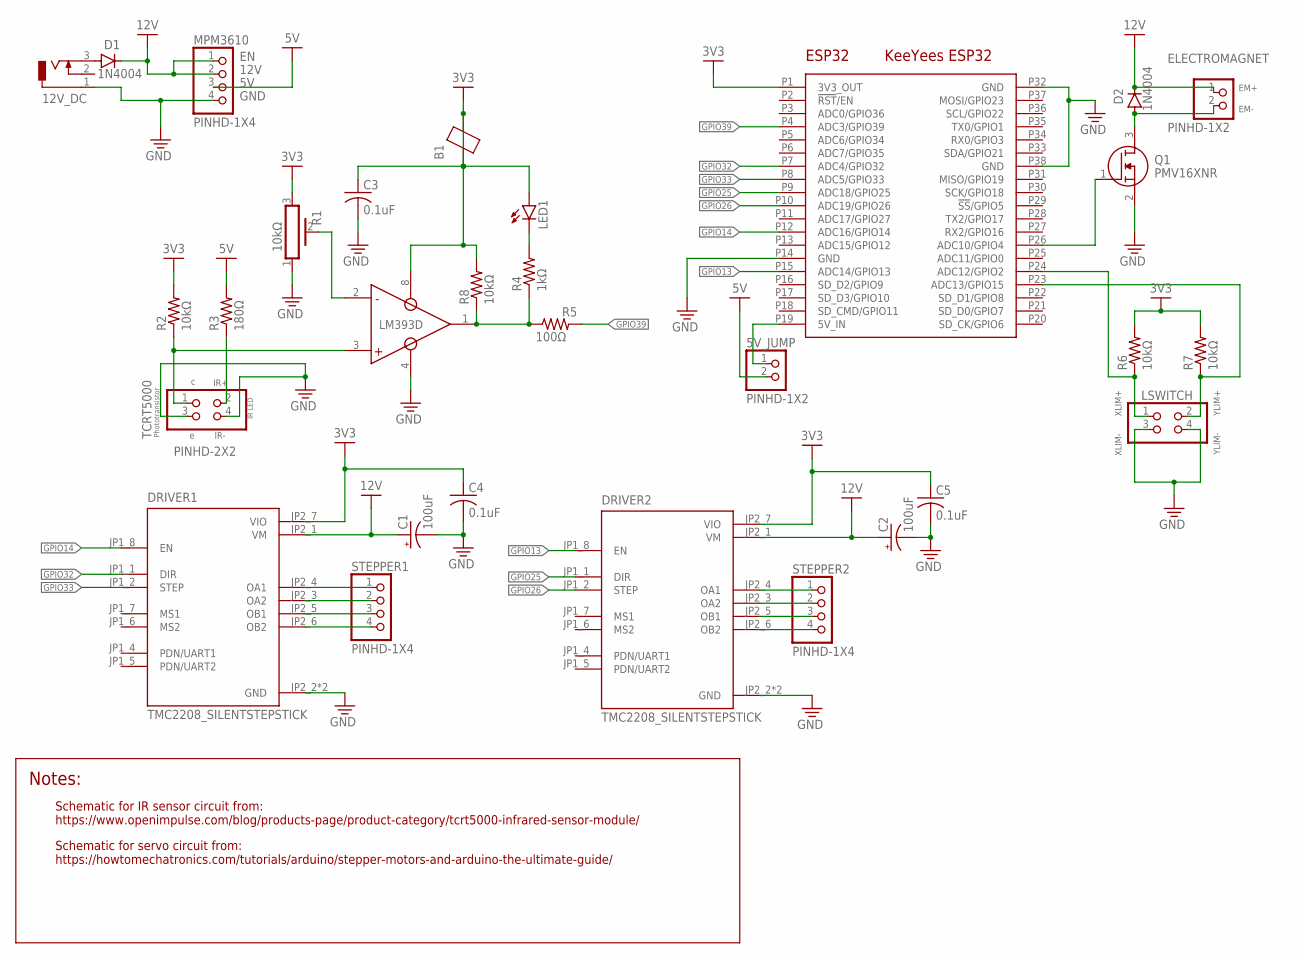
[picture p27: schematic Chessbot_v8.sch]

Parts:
5V_JUMP: PINHD-1X2; 1X02
12V_DC: DCJ0303
B1: BEAD0805; 0805
C1, C2: 100uF; E2,5-6
C3, C4, C5: 0.1uF; C0805
D1, D2: 1N4004; DO41-10
DRIVER1, DRIVER2: TMC2208_SILENTSTEPSTICK; MODULE_TMC2208_SILENTSTEPSTICK
ELECTROMAGNET: PINHD-1X2; 1X02
ESP32: KEEYEES_ESP32
LED1: LEDSMT1206; 1206
LSWITCH: PINHD-2X2; 2X02
MPM3610: PINHD-1X4; 1X04
Q1: PMV16XNR; SOT95P230X110-3N
R1: 10kΩ; PV36Z
R2, R6, R7, R8: 10kΩ; R0805
R3: 180Ω; R0805
R4: 1kΩ; R0805
R5: 100Ω; R0805
STEPPER1, STEPPER2: PINHD-1X4; 1X04
TCRT5000: PINHD-2X2; 2X02
U$2: LM393D

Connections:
3V3: B1.1, B1.2, C3.1, C4.1, C5.1, DRIVER1.JP2_7 (VIO), DRIVER2.JP2_7 (VIO), ESP32.P1 (3V3_OUT), LED1.A, R1.3, R2.2, R6.2, R7.2, R8.2, U$2.8 (VCC)
5V: 5V_JUMP.2, MPM3610.3, R3.2
12V: C1.+, C2.+, D1.C, D2.C, DRIVER1.JP2_1 (VM), DRIVER2.JP2_1 (VM), ELECTROMAGNET.1, MPM3610.1, MPM3610.2
GND: 12V_DC.1, C1.-, C2.-, C3.2, C4.2, C5.2, DRIVER1.JP2_2 (GND), DRIVER1.JP2_8 (GND), DRIVER2.JP2_2 (GND), DRIVER2.JP2_8 (GND), ESP32.P14 (GND), ESP32.P32 (GND), ESP32.P38 (GND), LSWITCH.3, LSWITCH.4, MPM3610.4, Q1.2 (S), R1.1, TCRT5000.3, TCRT5000.4, U$2.4 (GND)
GPIO13: DRIVER2.JP1_8 (EN), ESP32.P15 (ADC14/GPIO13)
GPIO14: DRIVER1.JP1_8 (EN), ESP32.P12 (ADC16/GPIO14)
GPIO25: DRIVER2.JP1_1 (DIR), ESP32.P9 (ADC18/GPIO25)
GPIO26: DRIVER2.JP1_2 (STEP), ESP32.P10 (ADC19/GPIO26)
GPIO32: DRIVER1.JP1_1 (DIR), ESP32.P7 (ADC4/GPIO32)
GPIO33: DRIVER1.JP1_2 (STEP), ESP32.P8 (ADC5/GPIO33)
GPIO39: ESP32.P4 (ADC3/GPIO39), R5.2
unnamed: R1.2, U$2.2 (IN-)
unnamed: DRIVER1.JP2_4 (OA1), STEPPER1.1
unnamed: DRIVER1.JP2_3 (OA2), STEPPER1.2
unnamed: R3.1, TCRT5000.2
unnamed: DRIVER1.JP2_5 (OB1), STEPPER1.3
unnamed: R2.1, TCRT5000.1, U$2.3 (IN+)
unnamed: DRIVER1.JP2_6 (OB2), STEPPER1.4
unnamed: DRIVER2.JP2_4 (OA1), STEPPER2.1
unnamed: D2.A, ELECTROMAGNET.2, Q1.3 (D)
unnamed: DRIVER2.JP2_3 (OA2), STEPPER2.2
unnamed: DRIVER2.JP2_5 (OB1), STEPPER2.3
unnamed: DRIVER2.JP2_6 (OB2), STEPPER2.4
unnamed: 5V_JUMP.1, ESP32.P19 (5V_IN)
unnamed: LED1.C, R4.2
unnamed: 12V_DC.3, D1.A
unnamed: R4.1, R5.1, R8.1, U$2.1 (OUT)
unnamed: ESP32.P26 (ADC10/GPIO4), Q1.1 (G)
unnamed: ESP32.P24 (ADC12/GPIO2), LSWITCH.1, R6.1
unnamed: ESP32.P23 (ADC13/GPIO15), LSWITCH.2, R7.1

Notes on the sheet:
12V
GND
EM+
EM-
IR+
IR-
Phototransistor
IR LED
Schematic for IR sensor circuit from: https://www.openimpulse.com/blog/products-page/product-category/tcrt5000-infrared-sensor-module/
Schematic for servo circuit from: https://howtomechatronics.com/tutorials/arduino/stepper-motors-and-arduino-the-ultimate-guide/
XLIM+
XLIM-
YLIM+
YLIM-

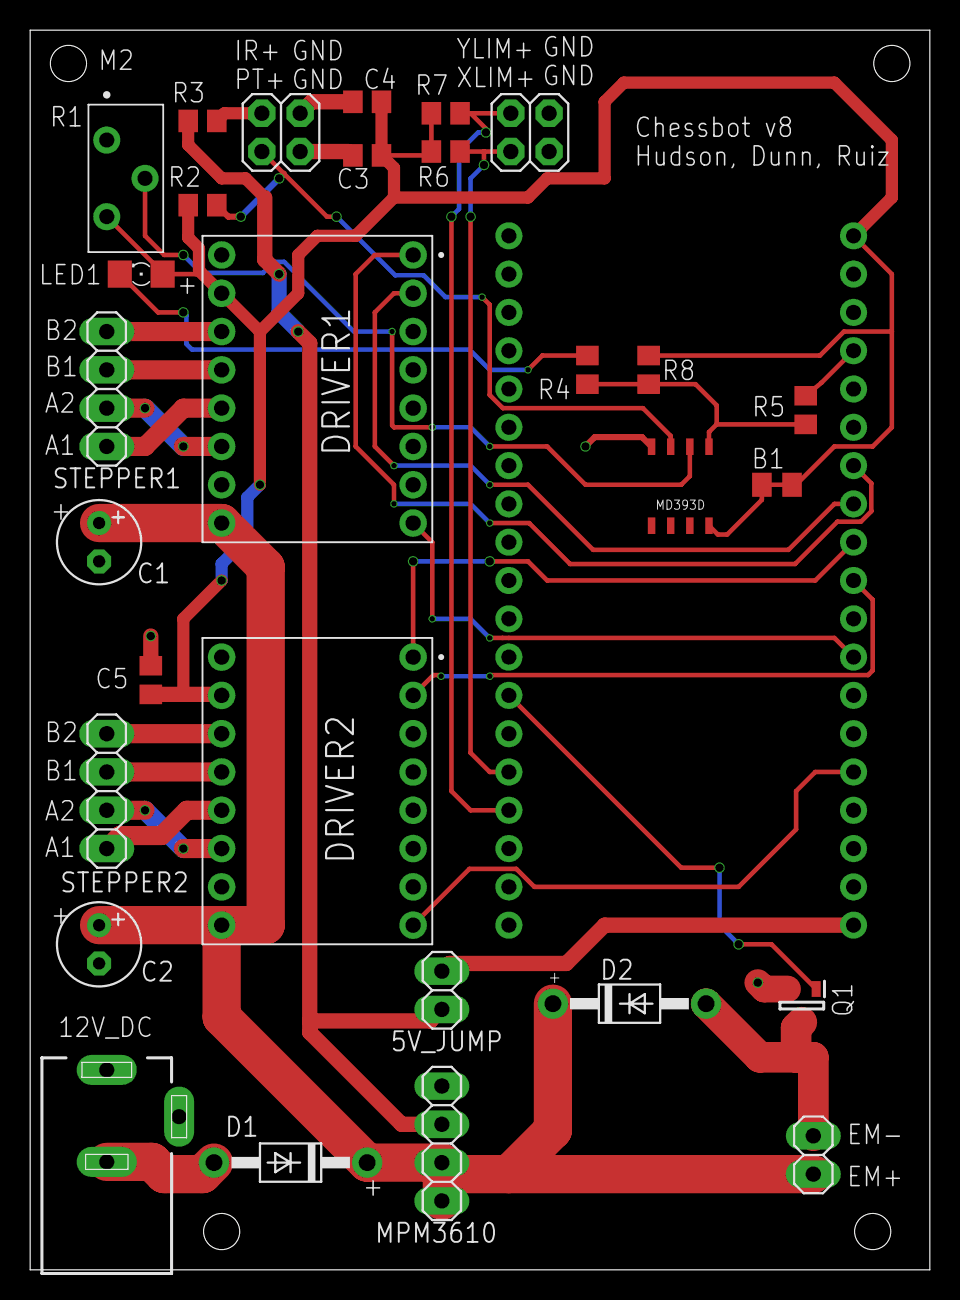
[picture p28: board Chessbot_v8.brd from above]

Board: 2 copper layers, 59.7 x 82.2 mm, 30 parts (1 on the bottom side), 30 nets.

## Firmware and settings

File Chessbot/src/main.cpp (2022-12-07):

/**
 * @file main.cpp
 * @author Sam Hudson, Dylan Ruiz, Scott Dunn
 * @brief Main file for controlling the ChessBot
 * @version 1.0
 * @date 2022-12-06
 *
 */
#include <Arduino.h>
#include "taskshare.h" // Header for inter-task shared data
#include "taskqueue.h" // Header for inter-task data queues
#include "shares.h"    // Header for shares used in this project
#include "objects/MotorDriver.h"
#include "objects/APIHandler.h"
#include "tasks/ControllerTask.h"
#include "tasks/MotorTask.h"
#include "tasks/FetchMoveTask.h"
#include "tasks/LimitSwitchTask.h"
#include "wifiPass.h"
#include "WiFi.h"

// Motor 1 pins
#define EN_PIN_1 14   // LOW: Driver enabled. HIGH: Driver disabled
#define STEP_PIN_1 33 // Step on rising edge
#define DIR_PIN_1 32

// Motor 2 pins
#define EN_PIN_2 13   // LOW: Driver enabled. HIGH: Driver disabled
#define STEP_PIN_2 26 // Step on rising edge
#define DIR_PIN_2 25

// Limit switch pins
#define XLIM_PIN 2
#define YLIM_PIN 15

// Solenoid pin
#define SOLENOID_PIN 4

// Sensor pin
#define SENSOR_PIN 39

/* Define Shares*/
Share<bool> stopMotor1("Stop Motor 1");
Share<bool> stopMotor2("Stop  Motor 2");
Share<bool> beginMove("Begin Move");
Queue<float> directionsQueue(5, "Directions Queue");
Share<uint16_t> steps1("No. of steps for Motor 1");
Share<uint16_t> steps2("No. of steps for Motor 2");
Share<float> velocity1("Steps/sec for Motor 1");
Share<float> velocity2("Steps/sec for Motor 2");
Share<int8_t> dirMotor1("Motor 1 Direction");
Share<int8_t> dirMotor2("Motor 2 Direction");
Share<uint8_t> startMotor1("Start Motor 1");
Share<uint8_t> startMotor2("Start Motor 2");
Share<bool> moveComplete("Move Complete");
Share<bool> startLimitx("Start Limit X");
Share<bool> startLimity("Start Limit Y");

// WiFi credentials (ssid and password is ignored by git for security)
const char *ssid = WIFI_SSID;                 // Import SSID from wifiPass.h
const char *password = WIFI_PASSWORD;         // Import password from wifiPass.h
const char *SSLCertificate = SSL_CERTIFICATE; // Import SSL certificate from wifiPass.h

// Create fetch move task object using APIHandler object
APIHandler apiHandler(SSLCertificate);
FetchMove fetchMoveTask(apiHandler);

// Create each motor driver object
Motor motor1(EN_PIN_1, STEP_PIN_1, DIR_PIN_1);
Motor motor2(EN_PIN_2, STEP_PIN_2, DIR_PIN_2);


// Create motor task objects using motor driver objects
MotorTask motorTask1(motor1, stopMotor1, dirMotor1, velocity1, steps1, startMotor1);
MotorTask motorTask2(motor2, stopMotor2, dirMotor2, velocity2, steps2, startMotor2);


// Create Limit Switch task object
LimitSwitchTask limitTask(XLIM_PIN, YLIM_PIN);

// Create main controller
Kinematics kinematics; // Create kinematics object for calculatons
Controller mainController(SOLENOID_PIN, SENSOR_PIN, kinematics);

/* --- Define tasks for FreeRTOS --- */

/**
 * @brief Task for controlling motor 1
 *
 * @param p_params void pointer for FreeRTOS setup
 */
void defMotorTask1(void *p_params)
{
  while (true)
  {
    motorTask1.run();
    vTaskDelay(20); // Task period
  }
}

/**
 * @brief Task for controlling motor 2
 *
 * @param p_params void pointer for FreeRTOS setup
 */
void defMotorTask2(void *p_params)
{
  while (true)
  {
    motorTask2.run();
    vTaskDelay(20); // Task period
  }
}

/**
 * @brief Task for main controller
 *
 * @param p_params void pointer for FreeRTOS setup
 */
void defControllerTask(void *p_params)
{
  while (true)
  {
    mainController.run();
    vTaskDelay(100); // Task period
  }
}

/**
 * @brief Task for fetching move from API
 *
 * @param p_params void pointer for FreeRTOS setup
 */
void defFetchMoveTask(void *p_params)
{
  while (true)
  {
    fetchMoveTask.run();
    vTaskDelay(1000); // Task period
  }
}

/**
 * @brief Task for checking limit switches
 *
 * @param p_params void pointer for FreeRTOS setup
 */
void defLimitTask(void *p_params)
{
  while (true)
  {
    limitTask.run();
    vTaskDelay(20); // Task period
  }
}

/* --- End of task definitions for FreeRTOS tasks --- */

/* --- Setup and begin multitasking --- */

/**
 * @brief Main program that sets up FreeRTOS tasks and starts the scheduler
 *
 */
void setup()
{
  Serial.begin(115200); // Begin serial monitor
  while (!Serial)
  {
  } // Wait for port to be ready before continuing

  // Connect to WiFi
  WiFi.mode(WIFI_STA);
  WiFi.begin(ssid, password);
  Serial.println("Connecting");
  while (WiFi.status() != WL_CONNECTED)
  {
    delay(500);
    Serial.print(".");
  }
  Serial.println("");
  Serial.print("Connected to WiFi network with IP Address: ");
  Serial.println(WiFi.localIP());

  // Setup pins
  pinMode(EN_PIN_1, OUTPUT);
  pinMode(STEP_PIN_1, OUTPUT);
  pinMode(XLIM_PIN, INPUT);
  pinMode(YLIM_PIN, INPUT);
  pinMode(SENSOR_PIN, INPUT);
  pinMode(SOLENOID_PIN, OUTPUT);

  // Start FreeRTOS tasks
  xTaskCreate(defMotorTask1, "Motor 1 Task", 10000, NULL, 3, NULL);
  xTaskCreate(defMotorTask2, "Motor 2 Task", 10000, NULL, 3, NULL);
  xTaskCreate(defControllerTask, "Controller Task", 10000, NULL, 2, NULL);
  xTaskCreate(defFetchMoveTask, "Fetch Move Task", 10000, NULL, 1, NULL);
  xTaskCreate(defLimitTask, "Limit Task", 4096, NULL, 3, NULL);
}

/**
 * @brief Main loop that does nothing (ensures FreeRTOS does not crash)
 *
 */
void loop()
{
  delay(60000);
};

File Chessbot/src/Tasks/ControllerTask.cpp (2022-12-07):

/**
 * @file Controller.cpp
 * @author Sam Hudson
 * @brief Provides the Main FSM, controls the actuator,
 * reads the IR sensor, and coordinates the movement of both motors
 * @version 1.0
 * @date 2022-11-10
 */

#include <Arduino.h>
#include "shares.h"
#include "tasks/ControllerTask.h"
#include "kinematics.h"
/**
 * @brief Construct a new Controller object
 *
 * @param SOLENOID_PIN Pin for the solenoid
 * @param SENSOR_PIN Pin for the IR sensor
 * @param kinematics Kinematics object for calculations
 */
Controller::Controller(uint8_t SOLENOID_PIN, uint8_t SENSOR_PIN, Kinematics kinematics)
{
    this->kinematics = kinematics; // Set kinematics object for calculations
    this->SOLENOID_PIN = SOLENOID_PIN;
    this->SENSOR_PIN = SENSOR_PIN;
    state = 0; // Start state = 0
    stepLength = .1;
    xCoordinateFrom = 0; // Define x coordinate of the piece to be moved
    yCoordinateFrom = 0; // Define y coordinate of the piece to be moved
    xCoordinateTo = 0; // Define x coordinate of the piece to be moved to
    yCoordinateTo = 0; // Define y coordinate of the piece to be moved to
    takePiece = 0; // If takePiece = 1, then a piece needs to be taken
    moveTake = 0; // If moveTake = 1, then a move to the piece is needed (for FSM control)
    xPieceGraveyard = 520; // x coordinate of the piece graveyard
    yPieceGraveyard = 522.5 - 180; // y coordinate of the piece graveyard
    sensorOffset = 18.25; // Offset for the IR sensor to the actuator magnet

    beginMove.put(false); // Ensure that no moves have started
    uint8_t count = 0;

    stateFlag2 = false;
    stateFlag3 = false;
    stateFlag6 = false;
    stateFlag8 = false;
    stateFlag10 = false;
    stateFlag11 = false;
    stateFlag12 = false;
    stateFlag13 = true;
}

/**
 * @brief Main FSM for the controller
 */
void Controller::run() // Method for FSM
{
    switch (state)
    {
    case 0: // Calibrate x axis
    {
        releasePiece(); // activates solenoid before moving under pieces
        origin_x();
        startLimitx.put(true);
        state = 1;
        stateFlag2 = true;
        break;
    }
    case 1: // Check if motors have stopped
    {
        if ((stopMotor1.get() == true, stopMotor2.get() == true))
        {
            if (stateFlag2)
            {
                state = 2;
                stateFlag2 = false;
            }
            else if (stateFlag3)
            {
                state = 3;
                stateFlag3 = false;
            }
            else if (stateFlag6)
            {
                state = 6;
                stateFlag6 = false;
            }
            else if (stateFlag8)
            {
                state = 8;
                stateFlag8 = false;
            }
            else if (stateFlag10)
            {
                state = 10;
                stateFlag10 = false;
            }
            else if (stateFlag11)
            {
                state = 11;
                stateFlag11 = false;
            }
            else if (stateFlag12)
            {
                state = 12;
                stateFlag12 = false;
            }
            else if (stateFlag13)
            {
                state = 13;
                stateFlag13 = false;
            }
        }
        break;
    }
    case 2: // Calibrate y axis
    {
        grabPiece(); // Releases Solenoid Activation
        origin_y();
        startLimity.put(true);
        state = 1; // Wait Motor State
        stateFlag3 = true;
        break;
    }

    case 3: // Check for a move request (waiting state)
    {
        if (moveTake == 1) // If a piece needs finished taking a piece
        {
            state = 5;
            moveTake = 0;
        }
        else if (beginMove.get() == true) // If a move is requested
        {
            state = 4;
            beginMove.put(false);    // Reset the flag
            moveComplete.put(false); // Tell API that move is not complete
        }
        break;
    }
    case 4: // Get new move from FetchMoveTask
    {
        takePiece = directionsQueue.get();       // First val defines if piece needs taking first
        xCoordinateFrom = directionsQueue.get(); // Second val defines x coordinate of piece to move
        yCoordinateFrom = directionsQueue.get(); // Third val defines y coordinate of piece to move
        xCoordinateTo = directionsQueue.get();   // Fourth val defines x coordinate of piece to move to
        yCoordinateTo = directionsQueue.get();   // Fifth val defines y coordinate of piece to move to
        state = 5;
        break;
    }
    case 5: //  Move piece to chess piece
    {
        releasePiece();     // activates solenoid before moving under pieces
        if (takePiece == 1) // If a piece needs taking
        {
            movePiece(0, xCoordinateTo - sensorOffset, 0, yCoordinateTo);
        }
        else
        {
            movePiece(0, xCoordinateFrom - sensorOffset, 0, yCoordinateFrom); // Move to piece
        }
        state = 1;
        stateFlag6 = true;
        break;
    }

    case 6: // Check if sensor is under piece
    {
        if (detectPiece())
        {
            count += 1;
        }
        if (count > 10) // should detect piece for 1 second before initiating move
        {
            state = 7;
        }
        break;
    }

    case 7: // Move actuator under piece
    {
        movePiece(0, sensorOffset, 0, 0); // Move to the right by the sensor offset
        state = 1;
        stateFlag8 = true;
        break;
    }

    case 8: // Grab piece
    {
        grabPiece();
        delay(50);
        state = 9;
        break;
    }

    case 9: // Move to grid before moving along gridlines (along x)
    {
        centerToGrid();
        state = 1;
        stateFlag10 = true;
        break;
    }

    case 10: // Move along x gridline
    {
        if (takePiece == 1) // If piece needs taking
        {
            xGridMove(xPieceGraveyard, xCoordinateTo);
            state = 1;
        }
        else
        {

            xGridMove(xCoordinateTo, xCoordinateFrom);
            state = 1;
        }
        stateFlag11 = true;

        break;
    }

    case 11: // Move along y gridline
    {
        if (takePiece == 1) // If piece needs taking
        {
            yGridMove(yPieceGraveyard, yCoordinateTo);
        }
        else
        {

            yGridMove(yCoordinateTo, yCoordinateFrom);
        }
        state = 1;
        stateFlag12 = true;
        break;
    }

    case 12: // Move piece along x for final position
    {
        if (takePiece) // If piece needs taking
        {
            gridToGraveyard(); // Take piece to graveyard along x
        }
        else
        {
            gridToCenter(); // Move piece to x center of sqaure from grid
        }

        state = 1;
        stateFlag13 = true;
        break;
    }
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

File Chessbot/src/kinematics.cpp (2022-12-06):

/**
 * @file kinematics.h
 * @author Dylan Ruiz
 * @brief Helper functions for calculating the coordination
 * of the motor movements
 * @version 1.0
 * @date 2022-12-06
 *
 */

#include <Arduino.h>
#include "kinematics.h"
/**
 * @brief Default constructor for a new Kinematics object
 *
 */
Kinematics::Kinematics()
{
}

/**
 * @brief Calculates the velocity of motor 1 based on the coordinates
 *
 * @param x_coordinate Desired x coordinate
 * @param y_coordinate Desired y coordinate
 * @return int16_t Required velocity of motor 1
 */
int16_t Kinematics::coordsToVelocityMotor1(float x_coordinate, float y_coordinate)
{
    if (y_coordinate == 0)
    {
        if (x_coordinate > 0)
        {
            return -1000; // quadrant 1
        }

        else
        {
            return 1000; // quadrant 3
        }
    }

    else if (x_coordinate == 0)
    {
        if (y_coordinate > 0)
        {
            return -1000; // quadrant 1
        }

        else
        {
            return 1000; // quadrant 3
        }
    }

    else if (abs(y_coordinate) > abs(x_coordinate)) // above 45 degree angles
    {
        if (y_coordinate / x_coordinate > 0) // Motor 1 Max
        {
            if (x_coordinate > 0) // sector 2
            {
                return -1000;
            }

            else // sector 6
            {
                return 1000;
            }
        }

        else
        {
            if (x_coordinate > 0) // sector 7
            {
                return -1000 * (1 + (y_coordinate / x_coordinate)) / (1 - (y_coordinate / x_coordinate));
            }

            else // sector 3
            {
                return 1000 * (1 + (y_coordinate / x_coordinate)) / (1 - (y_coordinate / x_coordinate));
            }
        }
    }

    else if (abs(y_coordinate) < abs(x_coordinate)) // below 45 degree angles
    {
        if (x_coordinate / y_coordinate > 0) // Motor 1 Max
        {
            if (x_coordinate > 0) // sector 1
            {
                return -1000;
            }

            else // sector 5
            {
                return 1000;
            }
        }

        else
        {
            if (x_coordinate > 0) // sector 8
            {
                return 1000 * ((x_coordinate / y_coordinate + 1) / (1 - x_coordinate / y_coordinate));
            }

            else // sector 4
            {
                return -1000 * ((x_coordinate / y_coordinate + 1) / (1 - x_coordinate / y_coordinate));
            }
        }
    }

    else if (abs(y_coordinate) == abs(x_coordinate)) // 45 degrees
    {
        if (y_coordinate / x_coordinate > 0)
        {
            if (x_coordinate > 0)
            {
                return -1000; // quadrant 1
            }

            else
            {
                return 1000; // quadrant 3
            }
        }

        else
        {
            return 0;
        }
    }

    return 0;
}

/**
 * @brief Calculates the velocity of motor 2 based on the coordinates
 *
 * @param x_coordinate Desired x coordinate
 * @param y_coordinate Desired y coordinate
 * @return int16_t Required velocity of motor 2
 */
int16_t Kinematics::coordsToVelocityMotor2(float x_coordinate, float y_coordinate)
{
    if (y_coordinate == 0)
    {
        if (x_coordinate > 0)
        {
            return -1000; // quadrant 1
        }

        else
        {
            return 1000; // quadrant 3
        }
    }

    else if (x_coordinate == 0)
    {
        if (y_coordinate > 0)
        {
            return 1000;
        }

        else
        {
            return -1000;
        }
    }

    else if (abs(y_coordinate) > abs(x_coordinate)) // above 45 degree angles
    {
        if (y_coordinate / x_coordinate > 0) // Motor 1 Max
        {
            if (x_coordinate > 0) // sector 2
            {
                return -1000 * (1 - (y_coordinate / x_coordinate)) / (1 + (y_coordinate / x_coordinate));
            }

            else // sector 6
            {
                return 1000 * (1 - (y_coordinate / x_coordinate)) / (1 + (y_coordinate / x_coordinate));
            }
        }

        else // Motor 2 Max
        {
            if (x_coordinate > 0) // sector 7
            {
                return -1000;
            }

            else // sector 3
            {
                return 1000;
            }
        }
    }

    else if (abs(y_coordinate) < abs(x_coordinate)) // below 45 degree angles
    {
        if (x_coordinate / y_coordinate > 0) // Motor 1 Max
        {
            if (x_coordinate > 0) // sector 1
            {
                return -1000 * ((x_coordinate / y_coordinate) - 1) / ((1 + (x_coordinate / y_coordinate)));
            }

            else // sector 5
            {
                return 1000 * ((x_coordinate / y_coordinate) - 1) / ((1 + (x_coordinate / y_coordinate)));
            }
        }

        else // Motor 2 Max
        {
            if (x_coordinate > 0) // sector 8
            {
                return -1000;
            }

            else // sector 4
            {
                return 1000;
            }
        }
    }

    else if (abs(y_coordinate) == abs(x_coordinate)) // 45 degrees
    {
        if (y_coordinate / x_coordinate < 0)
        {
            if (x_coordinate > 0)
            {
                return -1000; // quadrant 2
            }

            else
            {
                return 1000; // quadrant 4
            }
        }

        else
        {
            return 0;
        }
    }

    return 0;
}
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

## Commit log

2022-10-12 Added eagle project
    [chessbot.sch]
2022-10-12 first pack&go
    contains platform, linear rail and carriage
    [507_Chess_Bot.SLDASM, MGN12 LINEAR GUIDE RAIL, 600 mm.SLDPRT, MGN12H, LINEAR GUIDE BLOCK.SLDPRT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]
2022-10-12 update
    added the rail supports
    [507_Chess_Bot.SLDASM, platform rail mount.SLDPRT, rail rail mount.SLDPRT]
2022-10-13 Added Gantry Kinematics
2022-10-14 Chessbot board design v5
    New design with schematic and board.
    [Chessbot_v5.brd, Chessbot_v5.sch, chessbot.sch]
2022-10-15 v6 board - added limit switches
    [Chessbot_v6.brd, Chessbot_v6.sch]
2022-10-21 Board v7 design
    [Chessbot_v7.brd, Chessbot_v7.sch]
2022-10-23 Minor design alterations
    [Chessbot_v7.brd, Chessbot_v7.sch]
2022-10-23 DRC passed, CAM files
    [Chessbot_v7.GBL, Chessbot_v7.GBO, Chessbot_v7.GBP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]
2022-10-24 added the game board
    [507_Chess_Bot.SLDASM, game board.SLDPRT]
2022-10-25 V8 design
    [Chessbot_v8.brd, Chessbot_v8.sch]
2022-10-27 Chessbot v8 gerber
    [Chessbot_v7.GBL, Chessbot_v7.GBO, Chessbot_v7.GBP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]
2022-11-02 Parts lists
    [2022-10-30T175515.xlsx, 2022-10-30T183258.xlsx, Chessbot_v8 digikey order.csv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]
2022-11-09 Stepper mount design with updated system assembly
    [507_Chess_Bot.SLDASM, Arm.SLDPRT, Assembly - V-156-1C25 micro switch.SLDASM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]
2022-11-10 update
    added the MS1 and MS2 output definitions
    changed task kill to depend on limit switch state
    changed limit switch configurations in SW
    [507_Chess_Bot.SLDASM, Assembly - V-156-1C25 micro switch.SLDASM]
2022-11-11 Linear actuator Mount
    [507_Chess_Bot.SLDASM, Assembly - V-156-1C25 micro switch.SLDASM, Mount_Solenoid.SLDPRT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]
2022-11-14 fix: Bugs after merging mover branch
    [main.cpp]
2022-11-17 latest assembly
    [507_Chess_Bot.SLDASM, Assembly - V-156-1C25 micro switch.SLDASM, Solenoid JF-0826B.SLDPRT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]
2022-11-18 updated assembly and stepper mount
    [507_Chess_Bot.SLDASM, Assembly - V-156-1C25 micro switch.SLDASM, Stepper mount assembly.SLDASM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]
2022-11-19 stepper support update
    [507_Chess_Bot.SLDASM, Stepper mount assembly.SLDASM, platform rail mount stepper.SLDPRT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]
2022-11-19 updated the idler pulley support
    [507_Chess_Bot.SLDASM, GT2 idler pulley (5 mm bore) v1.SLDPRT, GT2_20T.SLDPRT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]
2022-11-24 Created Motor Task and updated Mover Task
2022-11-27 ScanBoard Task
    Finished Scan Board Task
2022-11-27 Added TCRT5000L model
    [TCR5000L.SLDPRT]
2022-11-27 updated full assembly and the rail to rail idler mounts
    [507_Chess_Bot.SLDASM, Assembly - V-156-1C25 micro switch.SLDASM, MGN12H, LINEAR GUIDE BLOCK.SLDPRT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]
2022-11-28 Solenoid mount update
    [Belt Clamp.SLDPRT, Mount_Solenoid.SLDPRT, Solenoid Mount.SLDPRT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]
2022-11-28 Belt clamp axis alignment
    [507_Chess_Bot.SLDASM, Belt Clamp.SLDPRT, Solenoid Mount.SLDPRT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]
2022-11-28 added a limit switch to a rail-rail idler mount and modified the actuator mount
    [507_Chess_Bot.SLDASM, Assembly - V-156-1C25 micro switch.SLDASM, Solenoid Mount.SLDPRT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]
2022-11-28 updated the assembly for the solenoid mounts
    [Assembly - V-156-1C25 micro switch.SLDASM, Belt Clamp.STL, Solenoid Mount.STL]
2022-12-01 Kinematics update
2022-12-01 Bug fixing on hardware
    [APIHandler.cpp, ControllerTask.cpp, FetchMoveTask.cpp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]
2022-12-01 fix: issue when starting with ongoing game
    [FetchMoveTask.cpp]
2022-12-01 Print statement changes
2022-12-02 fix api move complete issue
    [APIHandler.cpp, ControllerTask.cpp, FetchMoveTask.cpp]
2022-12-02 solenoid fix
2022-12-07 Updated Task Diagram and Kinematics
